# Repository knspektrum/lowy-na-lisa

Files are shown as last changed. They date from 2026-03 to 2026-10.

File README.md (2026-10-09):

# Łowy na Lisa

Gra terenowa dla dzieci oparta na LoRa - polega na znalezieniu ukrytych nadajnikiów ("lisów") wykorzystując siłę sygnału radiowego

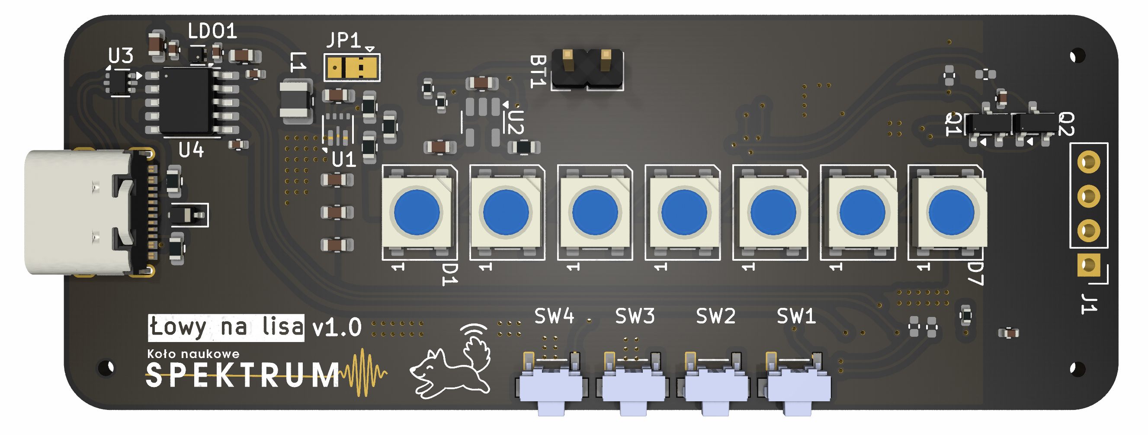
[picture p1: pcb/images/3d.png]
3D render PCB


## O projekcie

"Łowy na Lisa" to otwarty projekt hardware'owy tworzący ręczne urządzenia do polowania na nadajniki LoRa. Każdy uczestnik otrzymuje kompaktowe urządzenie wyposażone w:

- Wyświetlacz OLED z animowaną mascotką lisa (szczęśliwy smutny w zależności od siły sygnału)
- Pasek 7 diod WS2812B pokazujących kierunek i siłę sygnału
- 4 przyciski do obsługi menu
- Obsługę baterii LiPo z ładowaniem przez USB-C
- Tryb głębokiego snu dla długiej pracy na baterii

### Hardware
- **MCU:** CubeCell HTCC-AM01
- **LEDy:** 7x WS2812B NeoPixel (adresowalne)
- **Wyświetlacz:** 0.96" OLED I2C
- **Przyciski:** 4x na boku
- **Zasilanie:** Bateria LiPo ~500mAh + ładowarka TP4054
- **USB:** USB-C z konwerterem CH340K (programowanie)
- **Antena:** 868MHz, Własnoręcznie stworzona przez nas antena yagi (wczesniej zewnętrzna antena yagi telewizyjna) 
- **Wymiary:** Podłużna obudowa przyjazna dla dzieci

## Wersje

- [Odbiornik na PCB (CubeCell)](#pcb) - docelowa wersja na własnej płytce
- [Nadajnik ESP32](software/fox-transmitter/README.md) - "lis": WeMos D1 R32 + HM-TRLR-D-TTL-868, zasilanie 5x AA
- [Odbiornik ESP32](software/led-receiver/README.md) - ESP32 + Seeed LoRa-E5 + 7 diod, zasilanie LiPo
- [Flota i aktualizacje](software/ota/README.md) - strona w Chrome: które urządzenia ESP32 są włączone, na jakim kanale i programie; podpisane aktualizacje przez Bluetooth

<details>
<summary><b>Odbiornik na PCB (CubeCell)</b> - schemat i plot</summary>

Plot  |  Schemat
:-------------------------:|:-------------------------:
Plot  |  Schemat

Program: [software/receiver](software/receiver/receiver.ino)

</details>

<details>
<summary><b>Nadajnik ESP32</b> - schemat połączeń i kanały</summary>

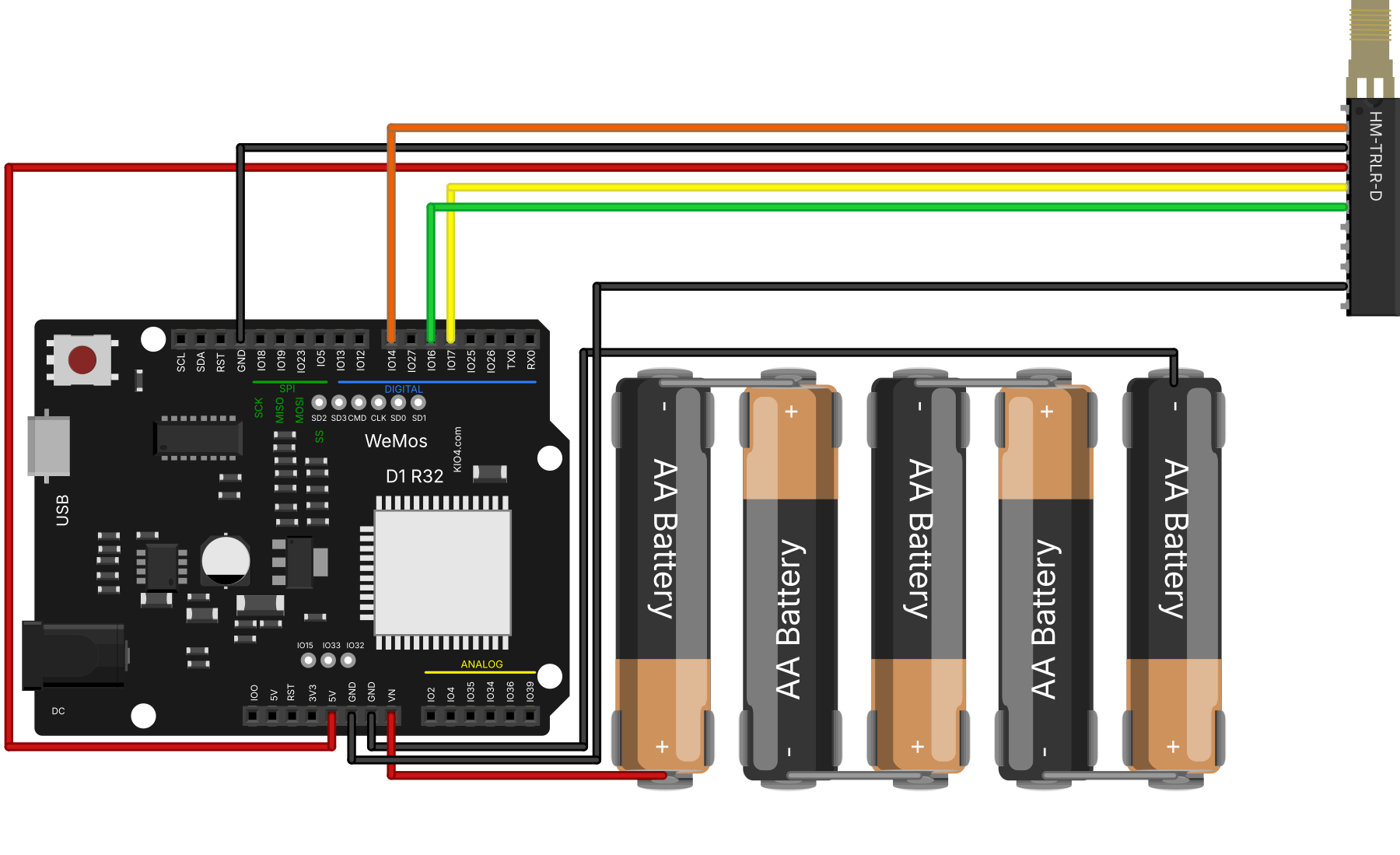
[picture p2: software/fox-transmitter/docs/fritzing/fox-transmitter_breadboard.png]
Nadajnik


D1 R32  |  HM-TRLR-D / baterie  |  Opis
:-------------------------:|:-------------------------:|:-------------------------
IO17 (TX)  |  RXD  |  komendy AT i dane do modułu
IO16 (RX)  |  TXD  |  odpowiedzi modułu
IO14  |  CONFIG  |  LOW = konfiguracja (AT), HIGH = nadawanie
5V  |  5V  |  zasilanie modułu
GND (górny, obok IO18)  |  GND (górny)  |
GND (dolny)  |  SLEEP  |  SLEEP na GND = moduł nie zasypia
VIN  |  + baterii 5x AA  |  ok. 7.5 V
GND (obok VIN)  |  - baterii  |

Id  |  Częstotliwość  |  Zworki CH_1-CH_4 (od góry)
:-------------------------:|:-------------------------:|:-------------------------:
1  |  863.0 MHz  |  ○ ○ ○ ○
2  |  863.5 MHz  |  ● ○ ○ ○
3  |  864.0 MHz  |  ○ ● ○ ○
4  |  864.5 MHz  |  ● ● ○ ○
5  |  865.0 MHz  |  ○ ○ ● ○
6  |  865.5 MHz  |  ● ○ ● ○
7  |  866.0 MHz  |  ○ ● ● ○
8  |  866.5 MHz  |  ● ● ● ○

Programowanie i szczegóły: [software/fox-transmitter](software/fox-transmitter/README.md)

</details>

<details>
<summary><b>Odbiornik ESP32</b> - schemat połączeń</summary>

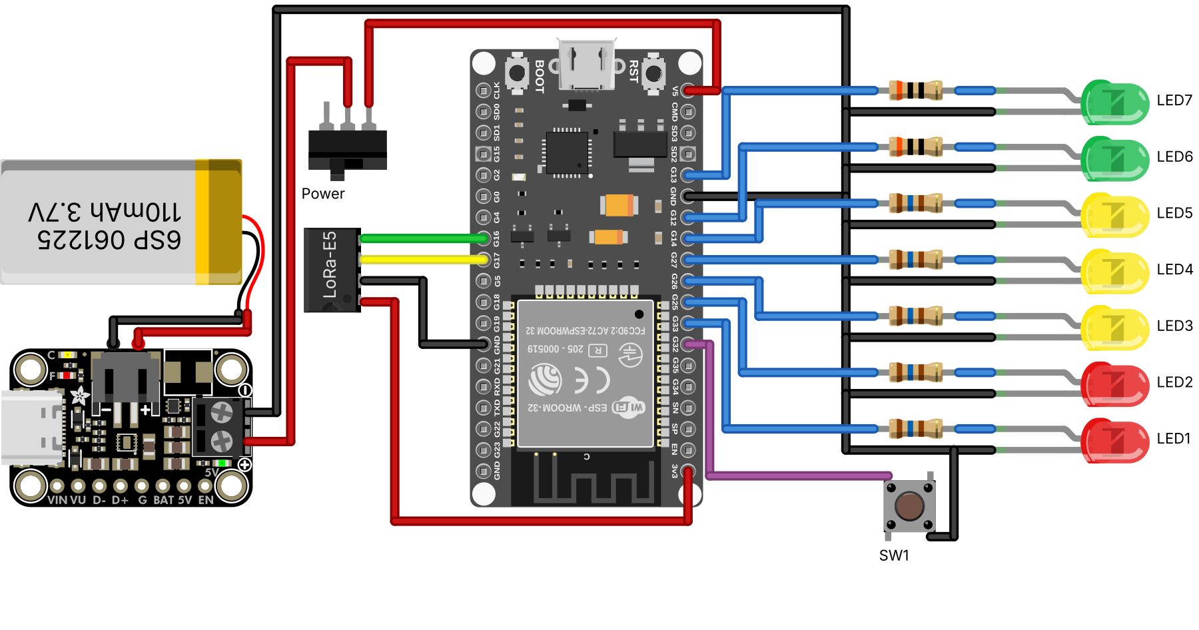
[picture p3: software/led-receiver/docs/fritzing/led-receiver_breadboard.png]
Odbiornik


ESP32  |  Element  |  Opis
:-------------------------:|:-------------------------:|:-------------------------
G33, G25  |  LED1, LED2 (czerwone)  |  rezystor 160 Ω
G26, G27, G14  |  LED3-LED5 (żółte)  |  rezystor 160 Ω
G12, G13  |  LED6, LED7 (zielone)  |  rezystor 30 Ω
G32  |  przycisk  |  drugi pin do GND
G17 (TX2)  |  LoRa-E5 RX (pad 9)  |  komendy AT
G16 (RX2)  |  LoRa-E5 TX (pad 10)  |  odpowiedzi i pakiety
3V3, GND  |  LoRa-E5 VCC (pad 1), GND (pad 2)  |
V5  |  wyłącznik → przetwornica 5 V → LiPo  |

Obsługa i programowanie: [software/led-receiver](software/led-receiver/README.md)

</details>

## PCB

Projekt PCB znajduje się w katalogu `pcb/` i jest przygotowany pod produkcję w JLCPCB (z PCBA assembly).

[Model 3D](pcb/lowy-na-lisa.stl)

Plot  |  Schemat
:-------------------------:|:-------------------------:
Plot  |  Schemat

## Historia projektu

### Faza 1: Eksperymenty
- Testy modułów nRF905 - działają ale brak RSSI
- Przejście na moduły HM-TRLR-D-TTL-868 (LoRa/FSK/GFSK + RSSI)
- Brute-forceowanie komend AT modemu LoRa

### Faza 2: Targi Hobby
- Pierwsza działająca wersja
- Testy z dziećmi - obudowa sprawdza się, anteny za duże
- Problem: nadajniki się zakłócały (rozwiązane: różne kanały)
- Pozytywne wrażenia: światełka wzbudzają zainteresowanie

### Faza 3: PCB
- Projekt PCB zintegrowanego z modułem CubeCell
- Optymalizacja pod baterię (deep sleep, odcięcie LEDów)
- Przygotowanie pod produkcję SMT w JLCPCB

## Pomysły/Plany na rozwój

- **Tryby gry:**
  - Zdobywanie nadajników (zbliżenie się + potwierdzenie przyciskiem)
  - Rywalizacja (broadcast pozycji na innym kanale)
  - Tryb fabularny z questami

- **Animacje:**
  - Lis wyskakujący z krzaka przy zbliżeniu do nadajnika
  - Wizualizacja siły sygnału na ekranie i LEDach
  - Różne stany emocjonalne mascotki

- **Hardware:**
  - Własnoręcznie robione anteny DIY
  - Ulepszona obudowa z integracją PCB
  - Druk 3D

## Autorzy

- Hubert Mucha - Antena
- Antoni Sacewicz - Antena
- Judyta Ferenc - Antena
- Antoni Antosik - obudowa 3D
- Adrian Bruch - Animacje i interfejs ekranu
- Katarzyna Rybarkiewicz - Lider, Projekt PCB
- Maximilian Gaedig - Aktualny Lider, Projekt PCB, Software
# na rekrutacji

wiktor kandulski, discord: kandul - marketing, kolaboracja z harcerstwem
tymoteusz majorek, discord: tymoteuszu - materiały marketingowe/instrukcje - pisanie zaawansowane (pisał kśiążki), 3D
beata waligórska, discord: slaani. - animacje

## Licencja

GPLv3

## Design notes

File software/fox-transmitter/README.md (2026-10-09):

# Nadajnik ("lis")

Nadajnik wysyła co 100 ms pakiet LoRa ze swoim numerem (id 1-9). Odbiorniki ustawione na ten sam numer pokazują siłę jego sygnału na diodach. Id 9 wymaga binarnego trybu diod w odbiorniku.

Schemat połączeń

## Hardware
- **MCU:** WeMos D1 R32 (ESP32, format Arduino Uno)
- **Radio:** HopeRF HM-TRLR-D-TTL-868 (LoRa SF7, 125 kHz, 20 dBm, pakiety po 32 bajty)
- **Zasilanie:** 5x AA (ok. 7.5 V) na VIN i GND

## Połączenia

D1 R32  |  HM-TRLR-D  |  Opis
:-------------------------:|:-------------------------:|:-------------------------
IO17 (TX)  |  RXD  |  komendy AT i dane do modułu
IO16 (RX)  |  TXD  |  odpowiedzi modułu
IO14  |  CONFIG  |  LOW = tryb konfiguracji (AT), HIGH = nadawanie
5V  |  5V  |  moduł przyjmuje 3.3-5.5 V
GND (górny, obok IO18)  |  GND (górny)  |
GND (dolny)  |  SLEEP  |  SLEEP na GND = moduł nie zasypia

D1 R32  |  Baterie 5x AA  |  Opis
:-------------------------:|:-------------------------:|:-------------------------
VIN  |  +  |  ok. 7.5 V (nowe baterie do ok. 8 V)
GND (obok VIN)  |  -  |

Piny modułu od góry: STATUS, CONFIG, GND, 5V, RXD, TXD, GND, A_TX, B_RX, SLEEP, RESET. Na górze modułu jest gniazdo antenowe SMA (żeńskie). STATUS, drugi GND, A_TX, B_RX i RESET nie są podłączone.

## Kanały

Numer nadajnika (id) wyznacza kanał radiowy i zawartość pakietów:
- **Kanał:** id - 1, ustawiany tylko zworkami CH_1-CH_4 na module (żadna komenda AT go nie ustawia ani nie odczytuje)
- **Częstotliwość:** 863.0 MHz + 0.5 MHz × kanał
- **Sync word:** `CAFE` + 4× id + `BABE`, zapisany w module
- **Pakiet:** 32 bajty, każdy równy id

Id  |  Kanał |  Częstotliwość |  Sync word |  Kod binarny (LED4–LED7)
:---:|:---:|:---:|:---:|:---:
1 | 0 | 863.0 MHz | `CAFE01010101BABE` | `0001`
2 | 1 | 863.5 MHz | `CAFE02020202BABE` | `0010`
3 | 2 | 864.0 MHz | `CAFE03030303BABE` | `0011`
4 | 3 | 864.5 MHz | `CAFE04040404BABE` | `0100`
5 | 4 | 865.0 MHz | `CAFE05050505BABE` | `0101`
6 | 5 | 865.5 MHz | `CAFE06060606BABE` | `0110`
7 | 6 | 866.0 MHz | `CAFE07070707BABE` | `0111`
8 | 7 | 866.5 MHz | `CAFE08080808BABE` | `1000`
9 | 8 | 867.0 MHz | `CAFE09090909BABE` | `1001`

Odbiornik startuje na id 1, każde naciśnięcie przycisku przechodzi na następny numer, a po ostatnim wraca do 1. Liczbę numerów (domyślnie 7, maksymalnie 9 w trybie binarnym) i sposób ich wyświetlania ustawia się na [stronie floty](../ota/README.md); szczegóły w [software/led-receiver](../led-receiver/README.md#ustawienia). Kod binarny podano od LED4 do LED7: `1001` oznacza zapalone LED4 i LED7. Zamiast przycisku można wpisać cyfrę w monitorze portu szeregowego odbiornika.

### Zworki

Zworki od góry do dołu, ● = założona, ○ = brak (kanał zapisany binarnie: CH_1 = 1, CH_2 = 2, CH_3 = 4, CH_4 = 8):

Zworka | Id 1 | Id 2 | Id 3 | Id 4 | Id 5 | Id 6 | Id 7 | Id 8 | Id 9
:---:|:---:|:---:|:---:|:---:|:---:|:---:|:---:|:---:|:---:
CH_1 | ○ | ● | ○ | ● | ○ | ● | ○ | ● | ○
CH_2 | ○ | ○ | ● | ● | ○ | ○ | ● | ● | ○
CH_3 | ○ | ○ | ○ | ○ | ● | ● | ● | ● | ○
CH_4 | ○ | ○ | ○ | ○ | ○ | ○ | ○ | ○ | ●

## Bluetooth

Lis nadaje przez Bluetooth na [stronę](../ota/README.md) swój kanał, wersję programu i stan. Telefon z aplikacją do Bluetooth też go widzi i mógłby po sile sygnału namierzyć lisa, więc w **Ustawieniach** lisa na stronie można włączyć ukrywanie: lis milknie 10, 30 albo 60 minut po włączeniu. Domyślnie nie ukrywa się nigdy. Ukryty lis jest na stronie „wyłączony albo ukryty”; żeby go sprawdzić albo zaktualizować, trzeba go wyłączyć i włączyć. Lis nie milknie, dopóki strona jest z nim połączona albo trwa aktualizacja.

## Programowanie

1. Ustaw zworki CH_1-CH_4 dla wybranego id (tabela wyżej).
2. Podłącz D1 R32 przez USB i wgraj program (następne wersje można wgrywać przez Bluetooth, [software/ota](../ota/README.md)):
   ```bash
   software/ota/build.sh
   software/ota/usb-flash.sh transmitter /dev/ttyUSB0
   ```
3. Otwórz monitor portu szeregowego (115200 baud) i wpisz cyfrę id (1-9). Nadajnik odpowiada `updated transmitter id id=N sync_word=CAFE...BABE`.
4. Wpisz `w`, żeby zapisać ustawienia w module (`saved to flash`). Po każdym starcie program odczytuje sync word z modułu i używa zapisanego id.
5. Sprawdź na odbiorniku ustawionym na to samo id: diody pokazują siłę sygnału, a w monitorze odbiornika pojawia się `received packet ... packet_tx_id=N`.

## Pliki

- `fox-transmitter.ino` - program nadajnika (aktualizacje przez Bluetooth: biblioteka `software/libraries/LisekOta`)
- `docs/fritzing/` - schemat połączeń we Fritzingu (`fox-transmitter.fzz`), generowany przez `make_fzz.py`, eksport `build.sh`
- Płytka WeMos D1 R32 we Fritzingu: część autorstwa Petera Van Eppa ([forum Fritzing](https://forum.fritzing.org/t/looking-for-wemos-d1-r32-esp32-uno/14487)); moduł HM-TRLR-D jest narysowany jako ogólny układ SIP z pinami w tej samej kolejności co na module, gniazdo SMA to część "SMA Antenna Connector" Petera Van Eppa ([forum Fritzing](https://forum.fritzing.org/t/sma-female-connector-part/4688)), baterie jako 5 ogniw AA z biblioteki Fritzinga połączonych szeregowo

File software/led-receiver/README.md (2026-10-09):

# Odbiornik z diodami

Odbiornik nasłuchuje nadajnika o wybranym numerze (id 1-9) i pokazuje siłę jego sygnału na 7 diodach. Działa tak samo jak `software/receiver/receiver.ino`, tylko na ESP32 z modułem Seeed LoRa-E5 sterowanym komendami AT.

Schemat połączeń

## Hardware
- **MCU:** ESP32 DevKit (38 pinów, wersja szeroka)
- **Radio:** Seeed LoRa-E5 (STM32WLE5JC, firmware AT, UART 9600 baud)
- **LEDy:** 7x 5 mm: 2 czerwone, 3 żółte, 2 zielone
- **Przycisk:** zmiana numeru nadajnika
- **Zasilanie:** Bateria LiPo + płytka z ładowaniem USB-C i przetwornicą 5 V, wyłącznik na plusie

## Połączenia

ESP32  |  Element  |  Opis
:-------------------------:|:-------------------------:|:-------------------------
G33  |  LED1 (czerwona)  |  najsłabszy sygnał, rezystor 160 Ω
G25  |  LED2 (czerwona)  |  rezystor 160 Ω
G26  |  LED3 (żółta)  |  rezystor 160 Ω
G27  |  LED4 (żółta)  |  rezystor 160 Ω
G14  |  LED5 (żółta)  |  rezystor 160 Ω
G12  |  LED6 (zielona)  |  rezystor 30 Ω
G13  |  LED7 (zielona)  |  najsilniejszy sygnał, rezystor 30 Ω
G32  |  przycisk  |  drugi pin do GND (wewnętrzny pull-up)
G17 (TX2)  |  LoRa-E5 RX (pad 9, PB7)  |  komendy AT
G16 (RX2)  |  LoRa-E5 TX (pad 10, PB6)  |  odpowiedzi i odebrane pakiety
3V3  |  LoRa-E5 VCC (pad 1)  |
GND  |  LoRa-E5 GND (pad 2), katody LED, przycisk  |
V5  |  wyłącznik → wyjście 5 V przetwornicy  |  bateria → ładowarka/przetwornica → wyłącznik → V5

Każda dioda: pin → rezystor → anoda, katoda → GND. Antena do RFIO modułu (pad 15).

## Obsługa

- Po starcie odbiornik słucha nadajnika 1 (863.0 MHz)
- Krótkie naciśnięcie przycisku: następny nadajnik (po ostatnim kanale wraca do 1); przez 0.5 s diody pokazują nowe id
- Cyfra w monitorze portu szeregowego (115200 baud) robi to samo
- Liczba zapalonych diod (od LED1) = siła sygnału: (110 + RSSI) / 15
- Brak pakietu od wybranego nadajnika przez 1 s: diody gasną (nadajnik wysyła co 100 ms)
- Aktualizacja przez Bluetooth: diody zapalają się kolejno w miarę wgrywania

Kanały i ustawianie nadajników: [software/fox-transmitter](../fox-transmitter/README.md).

### Ustawienia

Ustawia się je tylko w **Ustawieniach** odbiornika na [stronie floty](../ota/README.md), więc nie da się ich zmienić przypadkiem na samym odbiorniku. Odbiornik pamięta je po wyłączeniu.

- **Liczba kanałów:** przez ile numerów nadajników przechodzi przycisk, domyślnie 7 (1-7)
- **Diody zwykłe** (domyślnie): zapala się tyle diod od LED7 w dół, ile wynosi id, więc najwyżej 7 kanałów
- **Diody binarne:** id zapisane dwójkowo, do 9 kanałów, ● = świeci

Id | LED4 (8) | LED5 (4) | LED6 (2) | LED7 (1) | Kod
:--:|:--:|:--:|:--:|:--:|:--:
1 | ○ | ○ | ○ | ● | `0001`
2 | ○ | ○ | ● | ○ | `0010`
3 | ○ | ○ | ● | ● | `0011`
4 | ○ | ● | ○ | ○ | `0100`
5 | ○ | ● | ○ | ● | `0101`
6 | ○ | ● | ● | ○ | `0110`
7 | ○ | ● | ● | ● | `0111`
8 | ● | ○ | ○ | ○ | `1000`
9 | ● | ○ | ○ | ● | `1001`

Jeśli wybrane id nie mieści się w nowych ustawieniach (mniej kanałów albo id 8–9 przy zwykłych diodach), odbiornik wraca do id 1.

## Programowanie

Pierwszy raz przez USB, potem przez Bluetooth ze strony floty: [software/ota](../ota/README.md).

```bash
software/ota/build.sh
software/ota/usb-flash.sh receiver /dev/ttyUSB0
```

## Pliki

- `led-receiver.ino` - program odbiornika (aktualizacje przez Bluetooth: biblioteka `software/libraries/LisekOta`)
- `docs/fritzing/` - schemat połączeń we Fritzingu (`led-receiver.fzz`), generowany przez `make_fzz.py` (wartości rezystorów: `R_RED_YELLOW`, `R_GREEN`), eksport `build.sh`
- Płytka ESP32 we Fritzingu: część `ESP32-38PinWide-fixed` autorstwa Thomasa Plunketta ([forum Fritzing](https://forum.fritzing.org/t/esp32-wroom-32u/12978)), z poprawionym opisem pinu CMD obok V5; LoRa-E5 jest narysowany jako ogólny układ SIP (piny od góry: TX, RX, GND, VCC), ładowarka jako Adafruit bq25185 + 5V boost
- Wspólne skrypty Fritzinga: `software/fritzing-lib/` (`make_fzz.py` sprawdza, czy przewody się nie krzyżują ani nie nakładają; masa może przechodzić pod przewodami diod)

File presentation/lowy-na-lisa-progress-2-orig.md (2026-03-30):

# Łowy na Lisa - Update 15.01.26

## targi hobby
- pierwsza działająca wersja/prezentacja dla dzieci
- zauważenie że antena za duża dla dzieci
- dobre wrażenie - obudowa poręczna
- dobra dekoracja
- swiatełka wzbudzały zainteresowanie

## nadajniki się zakłucały
- było tylko odróżnianie po id wysyłanym w pakiecie lora
- nadawały były na tym samym kanale
- prosty fix: różne kanały

## plany na przyszłość 

### ekran
- maskotka lisek
- wizualizacja sygnału (lisek smutny/sczęsliwy)
- zmiana kalibracji
- ekran z deltalami: snr/rssi / detale na main screen
- stan baterii
- hint obsługi

#### animacje
- animacja jak sie dojdzie do nadajnika będzie karton, karton się otworzy i lis wyskoczy

### własnoręcznie robione anteny DIY
- druty
- kable
- druk 3d :)

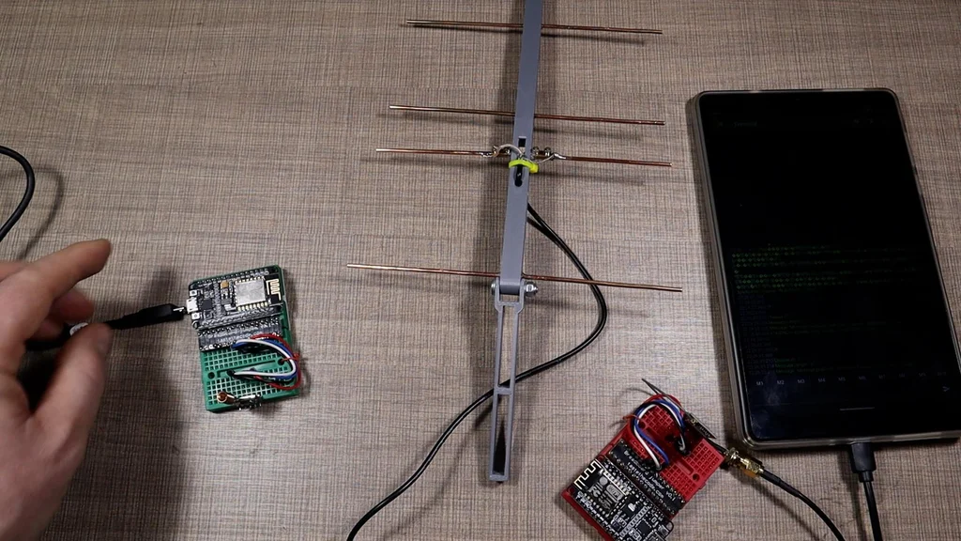
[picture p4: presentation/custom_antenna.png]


### kalibracja
- przy resetcie?

#### pomysły na zabawe
- zdobywanie nadajników (nadajnik blisko + potwierdzenie guzikiem) (przeskoczenie na następny kanał?)
- rywalizacja (broadcast aktualnego poziomu/nadajnika na innym kanale)
- story wymysleć

### polepszenie obudowy
- integracja pcb

### pcb
- stan baterii (voltage divider)
- ładowanie (moduł tpXXXX) + usb c
- Regulator LDO bateria -> 3.3v
- integracja z modułami CubeCell AM01
- podłączenie do anteny U.FL Receptacle jest już integrowane w CubeCell
- ledy + rezystory
- złącze na ekran
- złącza na guziki (reset + menu1 + menu2)

## dalszy plan
- 25.02.26 środa spotkanko 17:00 - pcb v1 i test antena
- 05.03.26 pcb final - zamówienie
- 25.03.26 spotkanko, zkładanie, lutowanie

## pytania?

## rozłożenie zadań
- animacje/pixelizacja liska - Adrian - do 15.03.26
- pcb - v1 Kasia - do 25.02.26 - muszę podać plan pinów 
- antena - Hubert + Antek - do 25.02.26 (blocked by order + druk (Max))
- programowanko - Adrian i Max - bez stanu bateri do 15.03.26 - dodanie stanu bateri do 30.03.26
- story - Antek
- obudowa - Antek3D (blocked by pcb (Kasia))
### cel - noc naukowców - wrzesień

## plan prezentacji
- Hubert - targi hobby
- Max - zakułucanie się nadajników
- Adrian - animacje/interfejs ekranu

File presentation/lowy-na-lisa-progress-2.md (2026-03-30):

---
theme:
  override:
    code:
      alignment: left
      background: false
---

Łowy na Lisa - Update 15.01.26
====
- targi hobby
- nadajniki się zakłucały
- plany na przyszłość

<!-- end_slide -->

targi hobby
===
- pierwsza działająca wersja/prezentacja dla dzieci
- zauważenie że antena za duża dla dzieci
- dobre wrażenie - obudowa poręczna
- dobra dekoracja
- swiatełka wzbudzały zainteresowanie

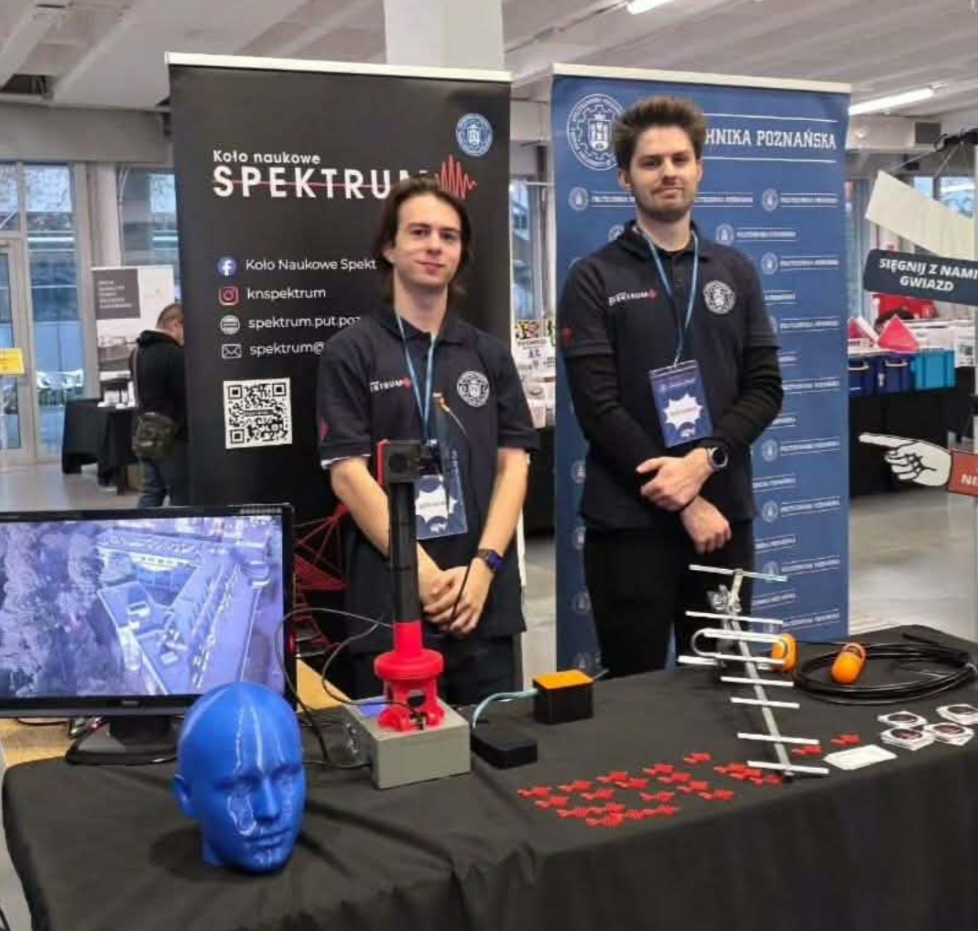
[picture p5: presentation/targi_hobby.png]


<!-- end_slide -->

nadajniki się zakłucały
===
- było tylko odróżnianie po id wysyłanym w pakiecie lora
- nadawały były na tym samym kanale
- prosty fix: różne kanały

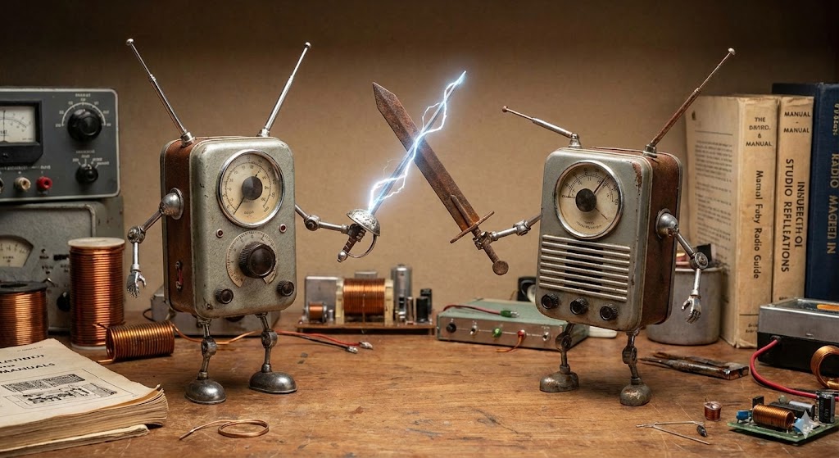
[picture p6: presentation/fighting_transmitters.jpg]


<!-- end_slide -->

plany na przyszłość
===
- ekran
- animacje
- antena
- pcb

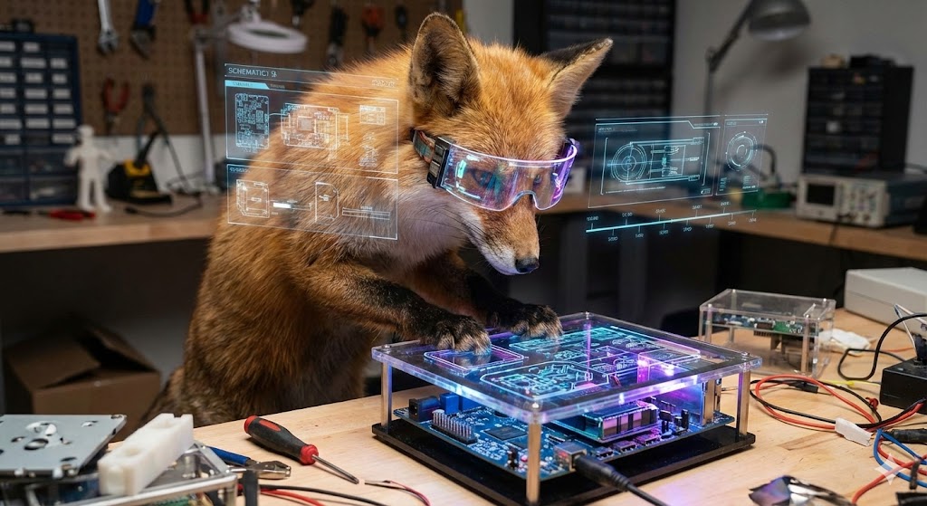
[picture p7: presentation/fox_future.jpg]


<!-- end_slide -->

ekran
===
- maskotka lisek
- wizualizacja sygnału (lisek smutny/sczęsliwy)
- zmiana kalibracji
- ekran z deltalami: snr/rssi / detale na main screen
- stan baterii
- hint obsługi

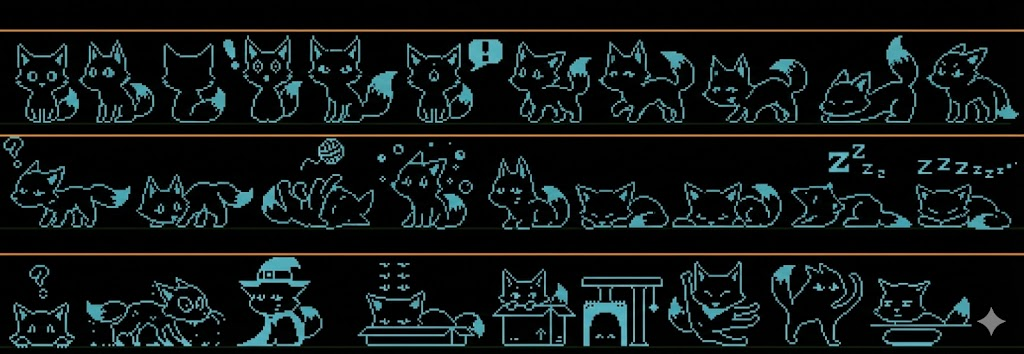
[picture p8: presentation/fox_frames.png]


<!-- end_slide -->

## własnoręcznie robione anteny DIY
- druty
- kable
- druk 3d :)



<!-- end_slide -->

#### pomysły na zabawe
- zdobywanie nadajników (nadajnik blisko + potwierdzenie guzikiem) (przeskoczenie na następny kanał?)
- rywalizacja (broadcast aktualnego poziomu/nadajnika na innym kanale)
- story wymysleć

## polepszenie obudowy
- integracja pcb

<!-- end_slide -->

pcb
===
- stan baterii (voltage divider)
- ładowanie (moduł tpXXXX) + usb c
- Regulator LDO bateria -> 3.3v
- integracja z modułami CubeCell AM01
- podłączenie do anteny U.FL Receptacle jest już integrowane w CubeCell
- ledy + rezystory
- złącze na ekran
- złącza na guziki (reset + menu1 + menu2)

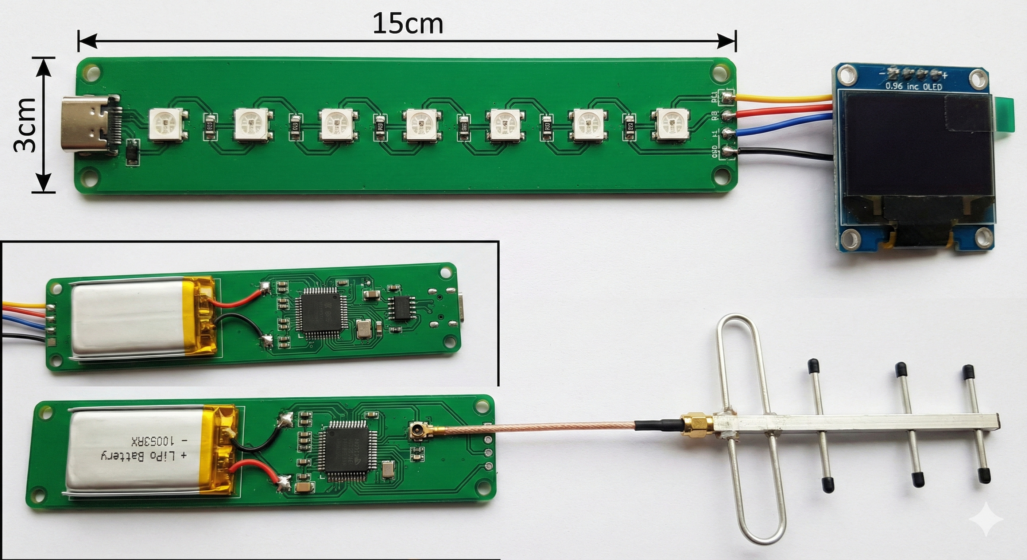
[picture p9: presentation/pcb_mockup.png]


<!-- end_slide -->

dalszy plan
===
- 25.02.26 środa spotkanko 17:00 - pcb v1 i test antena
- 05.03.26 pcb final - zamówienie
- 25.03.26 spotkanko, zkładanie, lutowanie
- wrzesień - noc naukowców

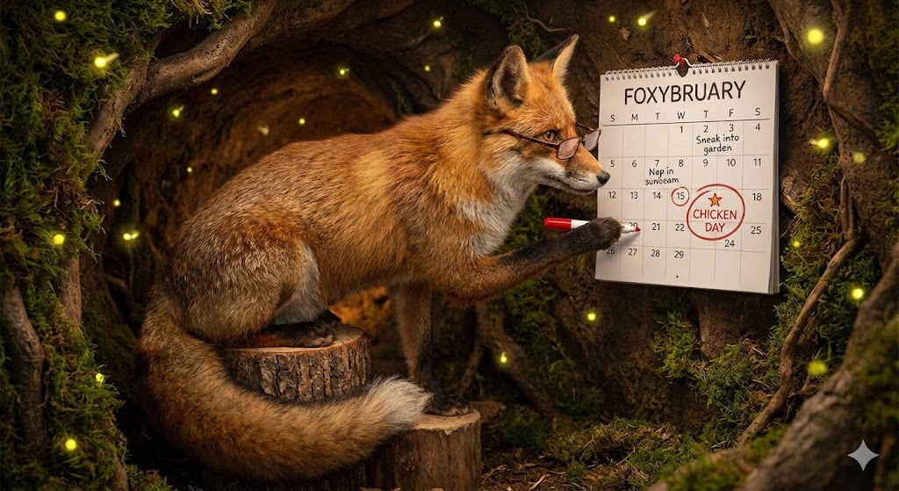
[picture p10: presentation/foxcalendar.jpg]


<!-- end_slide -->

# pytania?

<!-- end_slide -->

<!-- end_slide -->
<!-- end_slide -->
<!-- end_slide -->
<!-- end_slide -->

### cel - noc naukowców - wrzesień

<!-- end_slide -->

## kalibracja
- przy resetcie?
#### animacje
- animacja jak się jest blisko do nadajnika - będzie karton, karton się otworzy i lis wyskoczy

# rozłożenie zadań
- animacje/pixelizacja liska - Adrian - do 15.03.26
- pcb - v1 Kasia - do 25.02.26 - muszę podać plan pinów
- antena - Hubert + Antek - do 25.02.26 (blocked by order + druk (Max))
- programowanko - Adrian i Max - bez stanu bateri do 15.03.26 - dodanie stanu bateri do 30.03.26
- story - Antek
- obudowa - Antek3D (blocked by pcb (Kasia))

# plan prezentacji
- Hubert - targi hobby
- Max - zakułucanie się nadajników
- Adrian - animacje/interfejs ekranu

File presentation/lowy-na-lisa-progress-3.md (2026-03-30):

pomysł animacji: wyskakiwanie z krzaka 

Gemini
Analiza i poprawki projektu elektroniki
Conversation with Gemini
You said
co bys jescze dodal, analize mocnom

Gemini said
Projekt wygląda na fajny start (LoRa + RGB to klasyka "smart" gadżetów), ale diabeł tkwi w szczegółach, szczególnie przy zasilaniu bateryjnym. Masz tam kilka "pułapek", które mogą spalić komponenty lub rozładować baterię w jeden dzień.

Oto konkretna analiza i lista tego, co warto dodać/poprawić:

1. Krytyczne poprawki (Błędy w schemacie)
Kondensatory przy przyciskach (C1-C4): Masz wpisane 100µF. To o kilka rzędów wielkości za dużo. Standardowo do debouncingu (oddrgania styków) daje się 10nF - 100nF. Przy 100µF, w momencie naciśnięcia przycisku, następuje zwarcie dużego ładunku do masy, co z czasem wypali styki przycisku, a czas ładowania przez rezystor podciągający będzie trwał wieki.

Linia Reset: Dodaj rezystor podciągający (Pull-up, np. 10k) do 3.3V, chyba że moduł AM01 ma go już wewnętrznie (warto sprawdzić w datasheet, ale zewnętrzny to dobra praktyka dla stabilności).

Brak kondensatorów odsprzęgających: Przy pinie VDD procesora (AM01) i przy złączu wyświetlacza koniecznie dodaj kondensatory ceramiczne 100nF (i jeden 10µF blisko procka). Bez nich układ może się resetować przy skokach poboru prądu (np. podczas wysyłki pakietu LoRa).

2. Zarządzanie energią (Kluczowe przy baterii)
Odcięcie zasilania LED (VCC_LED): Diody WS2812B "piją" prąd (ok. 1mA na diodę) nawet gdy nie świecą (tzw. quiescent current). Przy 7 diodach masz 7mA stałego poboru, co zabije baterię 1000mAh w kilka dni bez robienia czegokolwiek.

Rozwiązanie: Dodaj tranzystor P-MOSFET (jako High-Side Switch), który pozwoli procesorowi całkowicie odciąć zasilanie od paska LED, gdy nie jest używany.

Dzielnik napięcia do baterii: Masz to w TODO. Użyj dużych rezystorów (np. 100k + 100k), żeby sam dzielnik nie rozładowywał baterii. Dodaj też tranzystor sterujący dzielnikiem lub kondensator 100nF przy pinie ADC, żeby pomiar był stabilny.

Level Shifter dla LED: WS2812B zasilane z 5V (Step-up) mogą nie wykryć sygnału 3.3V z procesora jako logicznej "jedynki" (wymagają ok. 0.7 * VCC).

Rozwiązanie: Prosty konwerter poziomów na jednym tranzystorze lub diodzie i rezystorze, żeby podbić sygnał GPIO2 do 5V.

3. Część RF (LoRa)
Tor antenowy (Pin 22): Na schemacie pin ANT jest pusty. Musisz tam dodać:

Złącze U.FL (IPEX) lub SMA.

Miejsce na tzw. Pi-network (trzy elementy: kondensator-cewka-kondensator), aby móc dopasować antenę do 50 Ohm. Nawet jeśli wlutujesz tam tylko zworkę 0 Ohm, miejsce na PCB musi być.

4. Co warto jeszcze dodać?
Zabezpieczenie przed odwrotną polaryzacją: Na złączu baterii (J3) łatwo o pomyłkę. Dodaj diodę Schottky’ego o niskim spadku napięcia lub (lepiej) tranzystor P-MOSFET jako zabezpieczenie.

Dioda statusowa LED (zwykła): Oprócz paska RGB, jedna mała dioda LED (np. na GPIO4) jest nieoceniona przy debugowaniu, gdy chcesz oszczędzać prąd i nie włączać całego paska ani wyświetlacza.

Piny I2C Pull-up: Jeśli Twój wyświetlacz (J1) nie ma wbudowanych rezystorów 4.7k na liniach SDA/SCL, musisz je dodać na schemacie.

USB-C i Ochrona ESD: Skoro planujesz USB, dodaj dedykowany układ zabezpieczający (ESD protection) na linie danych D+/D- oraz przyciski. To groszowe sprawy, a ratują procek przed ładunkami z palców.

5. Uwagi do TODO użytkownika
Step-Up na 5V: Pamiętaj, że przetwornice Step-Up wprowadzają szum. Daj spore kondensatory na wyjściu, żeby pasek LED nie zakłócał odczytów ADC lub komunikacji radiowej.

LDO: Wybierz model o bardzo niskim prądzie spoczynkowym (Low Iq), np. seria MCP1700 lub XC6206, jeśli urządzenie ma spać przez większość czasu.

Podsumowując: Najważniejsza rzecz teraz to zmiana tych kondensatorów 100µF przy buttonach na 100nF i dodanie odcięcia zasilania dla LEDów. Inaczej Twój projekt "zje" baterię szybciej, niż zdążysz wysłać pierwszy pakiet LoRa.

Czy chcesz, żebym pomógł Ci dobrać konkretne wartości rezystorów do dzielnika baterii lub zaprojektował schemat odcięcia zasilania LED na MOSFETcie?

Gemini is AI and can make mistakes, including about people. Your privacy and GeminiOpens in a new window

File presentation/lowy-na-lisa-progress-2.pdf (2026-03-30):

# Łowy na Lisa - Update 15.01.26

- targi hobby
- nadajniki się zakłucały
- plany na przyszłość

# targi hobby

- pierwsza działająca wersja/prezentacja dla dzieci
- zauważenie że antena za duża dla dzieci
- dobre wrażenie - obudowa poręczna
- dobra dekoracja
- swiatełka wzbudzały zainteresowanie

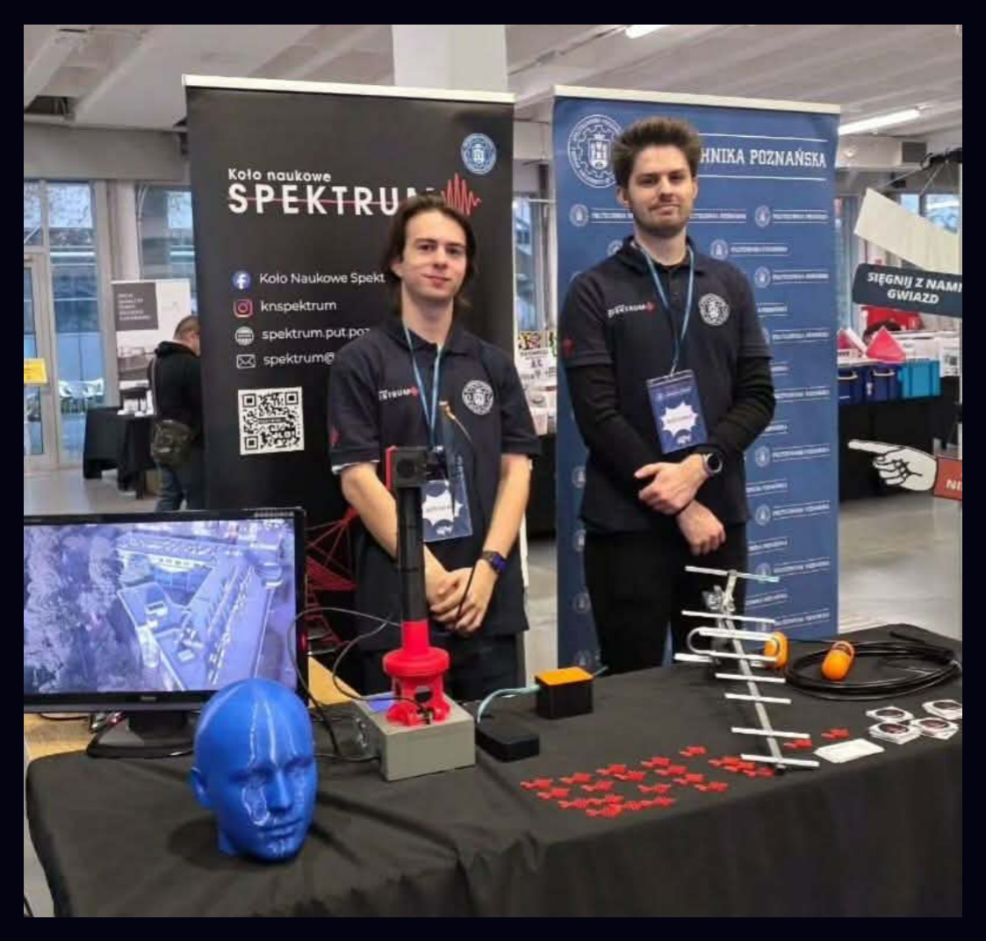
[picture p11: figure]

# nadajniki się zakłucały

- było tylko odróżnianie po id wysyłanym w pakiecie lora
- nadawały były na tym samym kanale
- prosty fix: różne kanały


# plany na przyszłość

- ekran
- animacje
- antena
- pcb

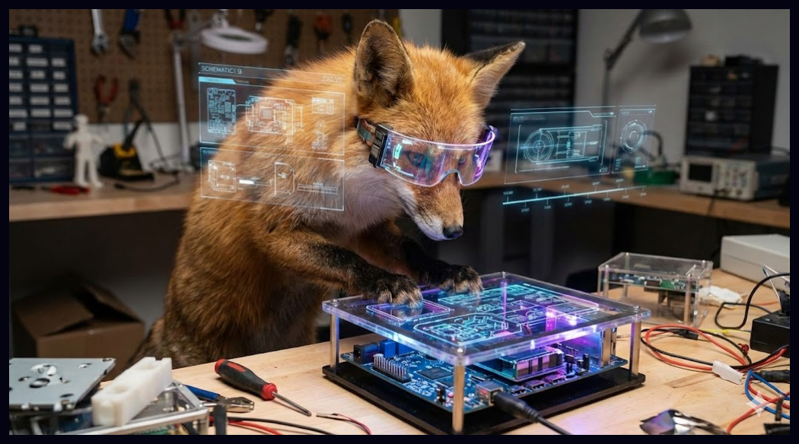
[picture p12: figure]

# ekran

- maskotka lisek
- wizualizacja sygnału (lisek smutny/sczęsliwy)
- zmiana kalibracji
- ekran z deltalami: snr/rssi / detale na main screen
- stan baterii
- hint obsługi

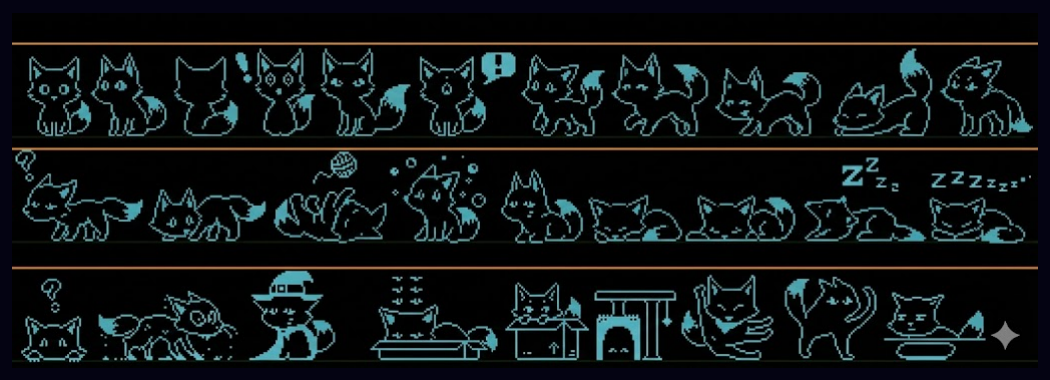
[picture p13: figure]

▓▓▓ własnoręcznie robione anteny DIY

- druty
- kable
- druk 3d :)


░░░░░ pomysły na zabawe

- zdobywanie nadajników (nadajnik blisko + potwierdzenie guzikiem) (przeskoczenie na następny kanał?)
- rywalizacja (broadcast aktualnego poziomu/nadajnika na innym kanale)
- story wymysleć

▓▓▓ polepszenie obudowy

- integracja pcb

# pcb

- stan baterii (voltage divider)
- ładowanie (moduł tpXXXX) + usb c
- Regulator LDO bateria -> 3.3v
- integracja z modułami CubeCell AM01
- podłączenie do anteny U.FL Receptacle jest już integrowane w CubeCell
- ledy + rezystory
- złącze na ekran
- złącza na guziki (reset + menu1 + menu2)

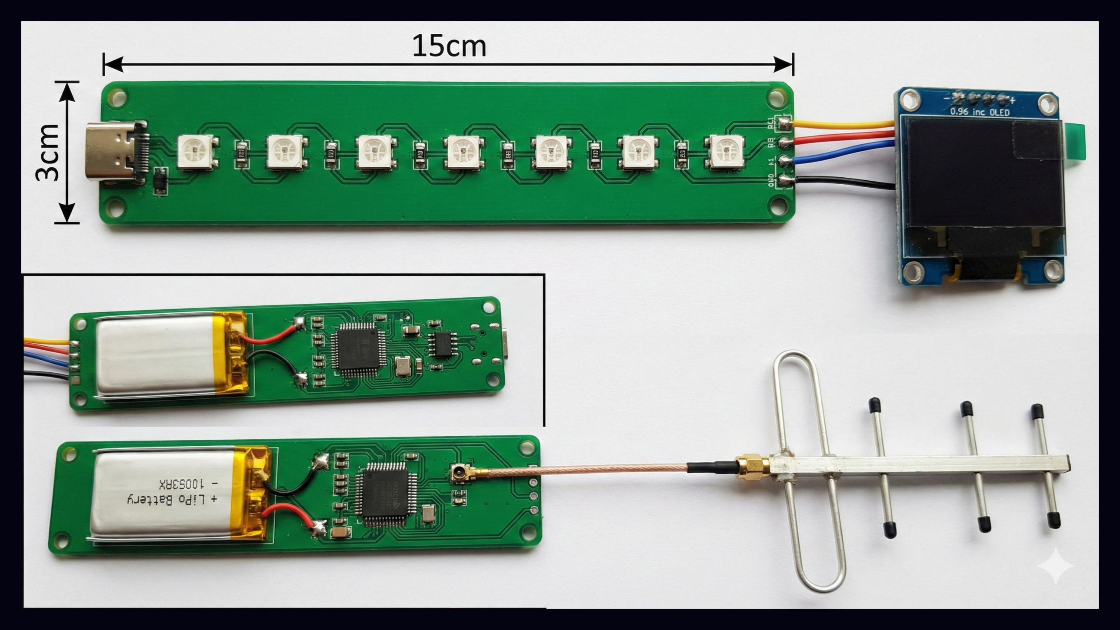
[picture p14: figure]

# dalszy plan

- 25.02.26 środa spotkanko 17:00 - pcb v1 i test antena
- 05.03.26 pcb final - zamówienie
- 25.03.26 spotkanko, zkładanie, lutowanie
- wrzesień - noc naukowców


██ pytania?

▒▒▒▒ cel - noc naukowców - wrzesień

▓▓▓ kalibracja

- przy resetcie?

░░░░░ animacje

- animacja jak się jest blisko do nadajnika - będzie karton, karton się otworzy i lis wyskoczy

██ rozłożenie zadań

- animacje/pixelizacja liska - Adrian - do 15.03.26
- pcb - v1 Kasia - do 25.02.26 - muszę podać plan pinów
- antena - Hubert + Antek - do 25.02.26 (blocked by order + druk (Max))
- programowanko - Adrian i Max - bez stanu bateri do 15.03.26 - dodanie stanu bateri do 30.03.26
- story - Antek
- obudowa - Antek3D (blocked by pcb (Kasia))

██ plan prezentacji

- Hubert - targi hobby
- Max - zakułucanie się nadajników
- Adrian - animacje/interfejs ekranu

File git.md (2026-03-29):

### Github

---

1. __Pobieranie zmian__
    - `git fetch`
    - `git pull`

---

2. __Wrzucenie wszystkich zmian__
    - `git add .`

    Lub wybrany folder/plik
    - `git add .\pcb\`

---

3. __Status__
    `git status`

---

4. __Commit__
    `git commit -m` __"wiadomość"__

---

5. __Push__
    `git push`

    Jeżeli nie przejdzie to:
    `git push origin main`

6. __Merge__
    1. `git add .` `git commit -m "moje zmiany"`
    
    2. `git fetch`
    
    3. `git merge origin/main`
    
    4. Rozwiązać konflikty
    
    5. `git push origin main --force-with-lease`

---

7. __Revert__
    1. Znależć hash commita np: `3cdeabb6d4475bf22c77ce93f576f29bd75ad27a`

    2. `git revert 3cdeabb6d4475bf22c77ce93f576f29bd75ad27a`

    3. Klikamy ESC a potem __:wq__ i enter. (VIM)

    4. `git push`

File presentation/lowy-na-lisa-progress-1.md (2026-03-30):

---
theme:
  override:
    code:
      alignment: left
      background: false
---

Coś działa
===

Moduły nrf905 działały odrazu po skonfigurowaniu przykładu z libki nrf905 na arduino, ale jeden kabel był podłączony w złym miejscu więc aż to działało mineły 2 dni.

Możemy spingować moduły, ale zawsze nam pokazują ten sam RTT bo różnica czasowa jest za mała by ją zarejestrować.

Niestety te moduły nie nadają się do naszych łowów...

<!-- end_slide -->

Nowe moduły!
===

<!-- column_layout: [1, 1] -->

<!-- column: 0 -->

# Doszły nam wczesniej

## nrf905

- działają, pingują się
- nie podają nam RSSI
- tylko działają na LoRa

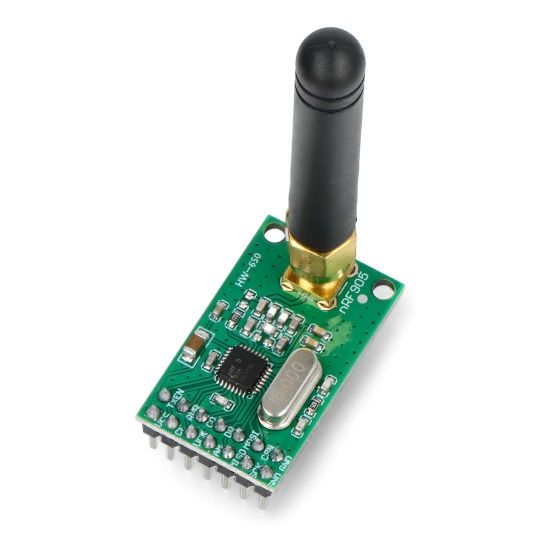
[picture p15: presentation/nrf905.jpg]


<!-- column: 1 -->

# Doszły nam pózniej

## HM-TRLR-D-TTL-868

- nie mamy jescze kodu dla nich
- mają różne modulacje - FSK, GFSK, LoRa
- powinny nam podawać moc odebranego sygnału
- miały przyjść wczesniej...

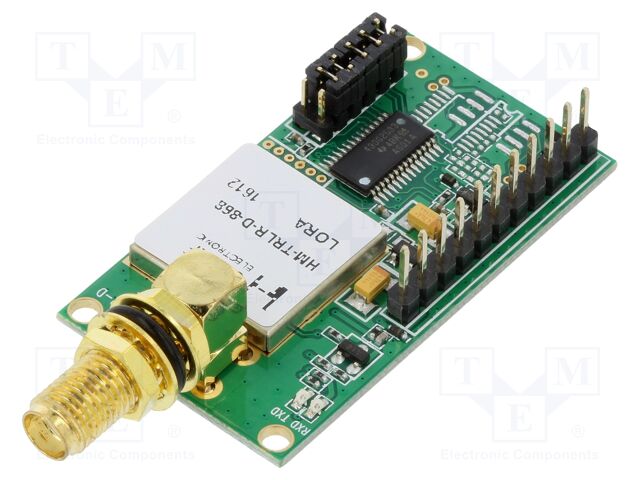
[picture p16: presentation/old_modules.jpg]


<!-- end_slide -->

Co teraz?
===

Zajmujemy się modułami HM-TRLR-D-TTL-868 i przepisujemy kod na te moduły.

Raczej powinniśmy się jescze zmieścic w terminie wczesniej założonym, skończyć pierwszą wersje przed końcem tego miesiąca.

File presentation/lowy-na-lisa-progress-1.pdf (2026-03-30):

# Coś działa

Moduły nrf905 działały odrazu po skonfigurowaniu przykładu z libki nrf905 na arduino, ale jeden kabel był podłączony w złym miejscu więc aż to działało mineły 2 dni.

Możemy spingować moduły, ale zawsze nam pokazują ten sam RTT bo różnica czasowa jest za mała by ją zarejestrować.

Niestety te moduły nie nadają się do naszych łowów...

# Nowe moduły!

██ Doszły nam wczesniej | ██ Doszły nam pózniej
▓▓▓ nrf905 | ▓▓▓ HM-TRLR-D-TTL-868
- działają, pingują się | • nie mamy jescze kodu dla nich
- nie podają nam RSSI | • mają różne modulacje - FSK,
- tylko działają na LoRa | GFSK, LoRa
| • powinny nam podawać moc
| odebranego sygnału
| • miały przyjść wczesniej...

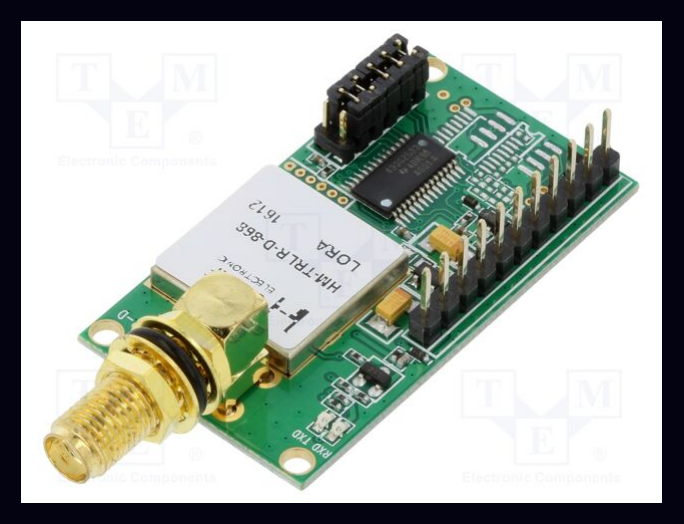
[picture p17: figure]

# Co teraz?

Zajmujemy się modułami HM-TRLR-D-TTL-868 i przepisujemy kod na te moduły.

Raczej powinniśmy się jescze zmieścic w terminie wczesniej założonym, skończyć pierwszą wersje przed końcem tego miesiąca.

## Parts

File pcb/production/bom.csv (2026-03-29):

Designator | Footprint | Quantity | Value | LCSC Part #
BT1 | PinHeader_1x02_P2.54mm_Vertical | 1 | 3.7V ~500mAh
C1, C10, C11, C16, C17, C18, C2, C3, C4, C8 | 0402 | 10 | 100n | C307331
C12, C5, C6, C7, C9 | 0603 | 5 | 10u | C19702
C13, C14, C15 | 0603 | 3 | 22u | C59461
D1, D2, D3, D4, D5, D6, D7 | LED_WS2812B_PLCC4_5.0x5.0mm_P3.2mm | 7 | WS2812B | C48586674
D8 | D_SOD-323 | 1 | B5819WS SL | C7420331
HTCC-AM1 | HTCC-AM01 | 1 | ~
J1 | PinHeader_1x04_P2.54mm_Vertical | 1 | Display
J3 | USB_C_Receptacle_G-Switch_GT-USB-7010ASV | 1 | USB_C_Receptacle_USB2.0_16P | C2988369
L1 | 1008 | 1 | 1uH (2-3A saturation) | C2849428
LDO1 | UDFN-4-1EP_1x1mm_P0.65mm_EP0.48x0.48mm | 1 | WL9005D4-33 | C5357206
Q1, Q2 | SOT-23 | 2 | AO3400A | C20917
R1 | 0603 | 1 | 2.4k | C22940
R10, R9 | 0402 | 2 | 1M | C26083
R2, R3 | 0603 | 2 | 5.1k | C23186
R4 | 0603 | 1 | 220k | C22961
R5 | 0402 | 1 | 470R | C25117
R6 | 0603 | 1 | 510k | C23192
R7 | 0603 | 1 | 100k | C25803
SW1, SW2, SW3, SW4 | SW_TS31-46-35-BK-B-160-RA-SMT-TR | 4 | TS24CA | C393942
U1 | Texas_RWU0007A_VQFN-7_2x2mm_P0.5mm | 1 | TPS61022 | C915088
U2 | SOT-23-5 | 1 | TP4054 | C32574
U3 | SOT-666 | 1 | USBLC6-2P6 | C2827693
U4 | SSOP-10-1EP_3.9x4.9mm_P1mm_EP2.1x3.3mm | 1 | CH340K | C968586

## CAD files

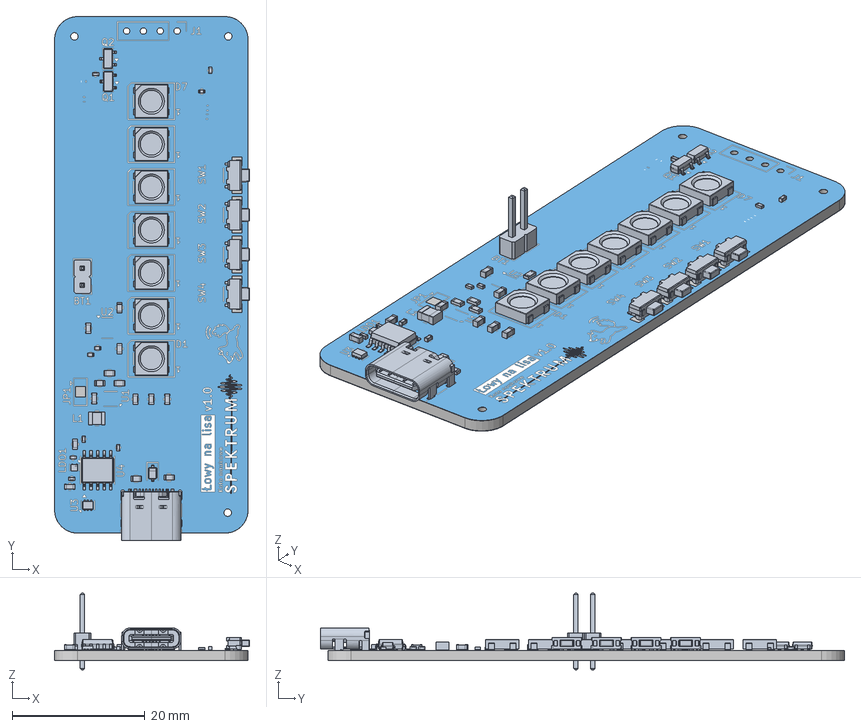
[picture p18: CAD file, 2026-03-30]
pcb/lowy-na-lisa.step
29.4 x 79.0 x 11.5 mm
SOT-23 x 2
TS31-46-35-BK-B-160-RA-SMT-TR x 4
R_0402_1005Metric x 3
C_0603_1608Metric x 8
R_0603_1608Metric x 6
LED_WS2812B_PLCC4_5.0x5.0mm_P3.2mm x 7
C_0402_1005Metric x 6
L_1008_2520Metric
PinHeader_1x02_P2.54mm_Vertical
USB_C_Receptacle_GCT_USB4105-xx-A_16P_TopMnt_Horizontal
SOT-666
D_SOD-323
UDFN-4-1EP_1x1mm_P0.65mm_EP0.48x0.48mm
SSOP-10-1EP_3.9x4.9mm_P1mm_EP2.1x3.3mm
lowy-na-lisa_silkscreen x 2
lowy-na-lisa_soldermask x 2
lowy-na-lisa_PCB

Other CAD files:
pcb/lowy-na-lisa.stl

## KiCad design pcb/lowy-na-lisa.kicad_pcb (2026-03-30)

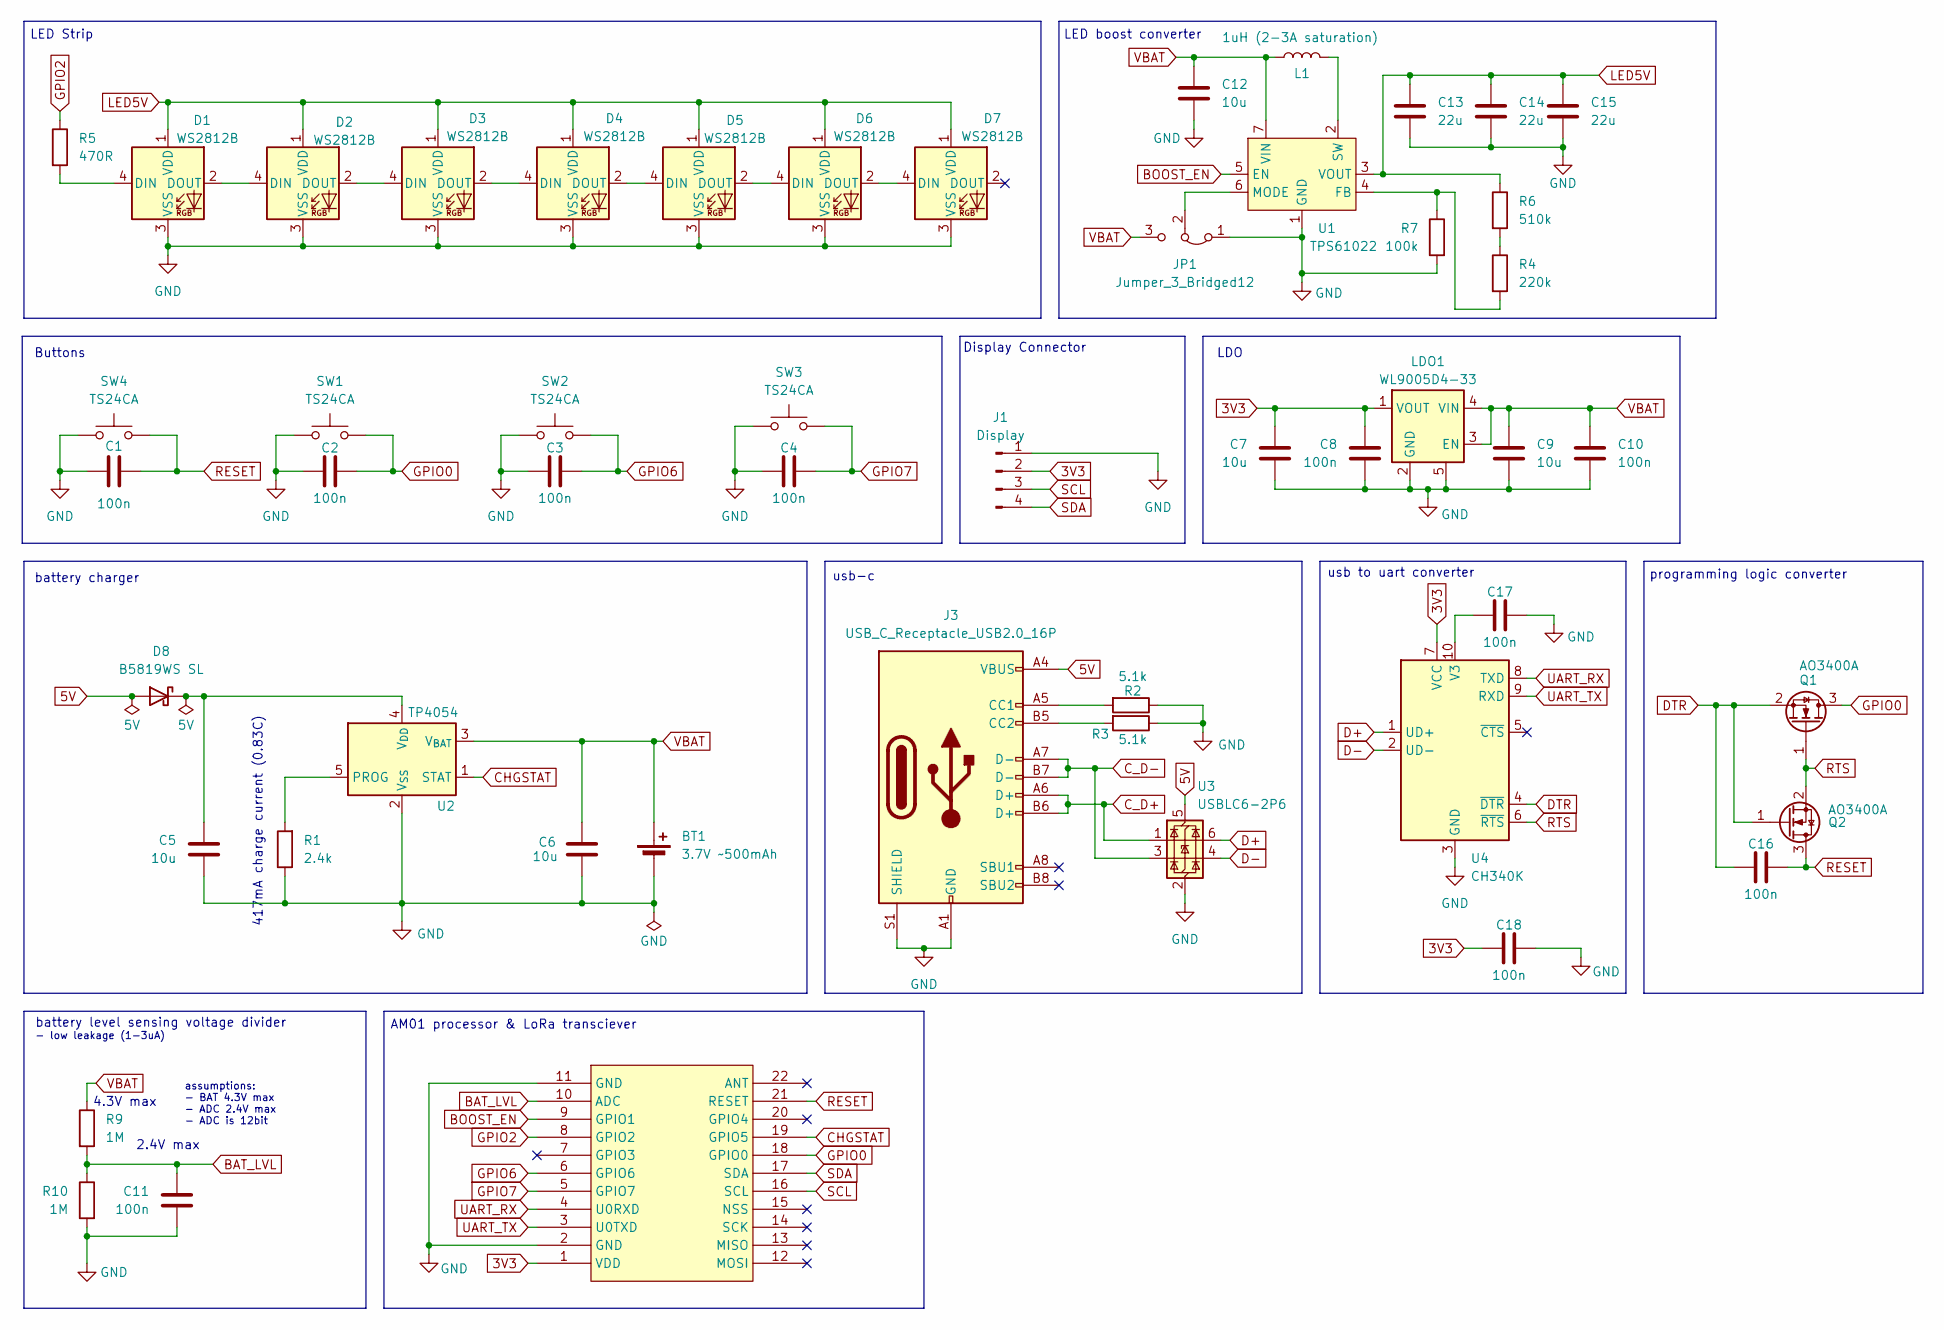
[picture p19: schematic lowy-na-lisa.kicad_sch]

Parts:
BT1: 3.7V ~500mAh; PinHeader_1x02_P2.54mm_Vertical
C1, C2, C3, C4, C8, C10, C11, C16, C17, C18: 100n; C_0402_1005Metric; LCSC C307331
C5, C6, C7, C9, C12: 10u; C_0603_1608Metric; LCSC C19702
C13, C14, C15: 22u; C_0603_1608Metric; LCSC C59461
D1, D2, D3, D4, D5, D6, D7: WS2812B; LED_WS2812B_PLCC4_5.0x5.0mm_P3.2mm; LCSC C48586674
D8: B5819WS SL; D_SOD-323; LCSC C7420331
HTCC-AM1: HTCC-AM01
J1: Display; PinHeader_1x04_P2.54mm_Vertical
J3: USB_C_Receptacle_USB2.0_16P; USB_C_Receptacle_G-Switch_GT-USB-7010ASV; LCSC C2988369
JP1: Jumper_3_Bridged12; SolderJumper-3_P1.3mm_Bridged2Bar12_Pad1.0x1.5mm
L1: 1uH (2-3A saturation); L_1008_2520Metric; LCSC C2849428
LDO1: WL9005D4-33; UDFN-4-1EP_1x1mm_P0.65mm_EP0.48x0.48mm; LCSC C5357206
Q1, Q2: AO3400A; SOT-23; LCSC C20917
R1: 2.4k; R_0603_1608Metric; LCSC C22940
R2, R3: 5.1k; R_0603_1608Metric; LCSC C23186
R4: 220k; R_0603_1608Metric; LCSC C22961
R5: 470R; R_0402_1005Metric; LCSC C25117
R6: 510k; R_0603_1608Metric; LCSC C23192
R7: 100k; R_0603_1608Metric; LCSC C25803
R9, R10: 1M; R_0402_1005Metric; LCSC C26083
SW1, SW2, SW3, SW4: TS24CA; SW_TS31-46-35-BK-B-160-RA-SMT-TR; LCSC C393942
U1: TPS61022; Texas_RWU0007A_VQFN-7_2x2mm_P0.5mm; LCSC C915088
U2: TP4054; SOT-23-5; LCSC C32574
U3: USBLC6-2P6; SOT-666; LCSC C2827693
U4: CH340K; SSOP-10-1EP_3.9x4.9mm_P1mm_EP2.1x3.3mm; LCSC C968586

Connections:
3V3: C7.1, C8.1, C18.1, HTCC-AM1.1 (VDD), J1.2, LDO1.1 (VOUT), U4.7 (VCC)
5V: D8.2 (A), J3.A4 (VBUS), J3.A9 (VBUS), J3.B4 (VBUS), J3.B9 (VBUS), U3.5 (VBUS)
BAT_LVL: C11.1, HTCC-AM1.10 (ADC), R9.2, R10.1
BOOST_EN: HTCC-AM1.9 (GPIO1), U1.5 (EN)
CHGSTAT: HTCC-AM1.19 (GPIO5), U2.1 (STAT)
C_D+: J3.A6 (D+), J3.B6 (D+), U3.1 (I/O1)
C_D-: J3.A7 (D-), J3.B7 (D-), U3.3 (I/O2)
D+: U3.6 (I/O1), U4.1 (UD+)
D-: U3.4 (I/O2), U4.2 (UD-)
DTR: C16.1, Q1.2 (S), Q2.1 (G), U4.4 (~DTR)
GND: BT1.2 (-), C1.1, C2.1, C3.1, C4.1, C5.2, C6.1, C7.2, C8.2, C9.2, C10.2, C11.2, C12.2, C13.2, C14.2, C15.2, C17.2, C18.2, D1.3 (VSS), D2.3 (VSS), D3.3 (VSS), D4.3 (VSS), D5.3 (VSS), D6.3 (VSS), D7.3 (VSS), HTCC-AM1.2 (GND), HTCC-AM1.11 (GND), J1.1, J3.A1 (GND), J3.A12 (GND), J3.B1 (GND), J3.B12 (GND), J3.S1 (SHIELD), JP1.1 (A), LDO1.2 (GND), LDO1.5, R1.1, R2.1, R3.1, R7.2, R10.2, SW1.1, SW2.1, SW3.1, SW4.1, U1.1 (GND), U2.2 (V_{SS}), U3.2 (GND), U4.3 (GND), U4.11 (GND)
GPIO0: C2.2, HTCC-AM1.18 (GPIO0), Q1.3 (D), SW1.2
GPIO2: HTCC-AM1.8 (GPIO2), R5.1
GPIO6: C3.2, HTCC-AM1.6 (GPIO6), SW2.2
GPIO7: C4.2, HTCC-AM1.5 (GPIO7), SW3.2
LED5V: C13.1, C14.1, C15.1, D1.1 (VDD), D2.1 (VDD), D3.1 (VDD), D4.1 (VDD), D5.1 (VDD), D6.1 (VDD), D7.1 (VDD), R6.1, U1.3 (VOUT)
unnamed: D1.4 (DIN), R5.2
unnamed: D1.2 (DOUT), D2.4 (DIN)
unnamed: D2.2 (DOUT), D3.4 (DIN)
unnamed: D3.2 (DOUT), D4.4 (DIN)
unnamed: D4.2 (DOUT), D5.4 (DIN)
unnamed: D5.2 (DOUT), D6.4 (DIN)
unnamed: D6.2 (DOUT), D7.4 (DIN)
unnamed: C5.1, D8.1 (K), U2.4 (V_{DD})
unnamed: J3.A5 (CC1), R2.2
unnamed: J3.B5 (CC2), R3.2
unnamed: JP1.2 (C), U1.6 (MODE)
unnamed: R4.1, R6.2
unnamed: R4.2, R7.1, U1.4 (FB)
unnamed: L1.2, U1.2 (SW)
unnamed: R1.2, U2.5 (PROG)
unnamed: C17.1, U4.10 (V3)
RESET: C1.2, C16.2, HTCC-AM1.21 (RESET), Q2.3 (D), SW4.2
RTS: Q1.1 (G), Q2.2 (S), U4.6 (~RTS)
SCL: HTCC-AM1.16 (SCL), J1.3
SDA: HTCC-AM1.17 (SDA), J1.4
UART_RX: HTCC-AM1.4 (U0RXD), U4.8 (TXD)
UART_TX: HTCC-AM1.3 (U0TXD), U4.9 (RXD)
VBAT: BT1.1 (+), C6.2, C9.1, C10.1, C12.1, JP1.3 (B), L1.1, LDO1.3 (EN), LDO1.4 (VIN), R9.1, U1.7 (VIN), U2.3 (V_{BAT})

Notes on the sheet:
usb to uart converter
LED Strip
LDO
Buttons
2.4V max
- low leakage (1-3uA)
programming logic converter
assumptions: - BAT 4.3V max - ADC 2.4V max - ADC is 12bit
battery level sensing voltage divider
LED boost converter
usb-c
417mA charge current (0.83C)
Display Connector
4.3V max
AM01 processor & LoRa transciever
battery charger

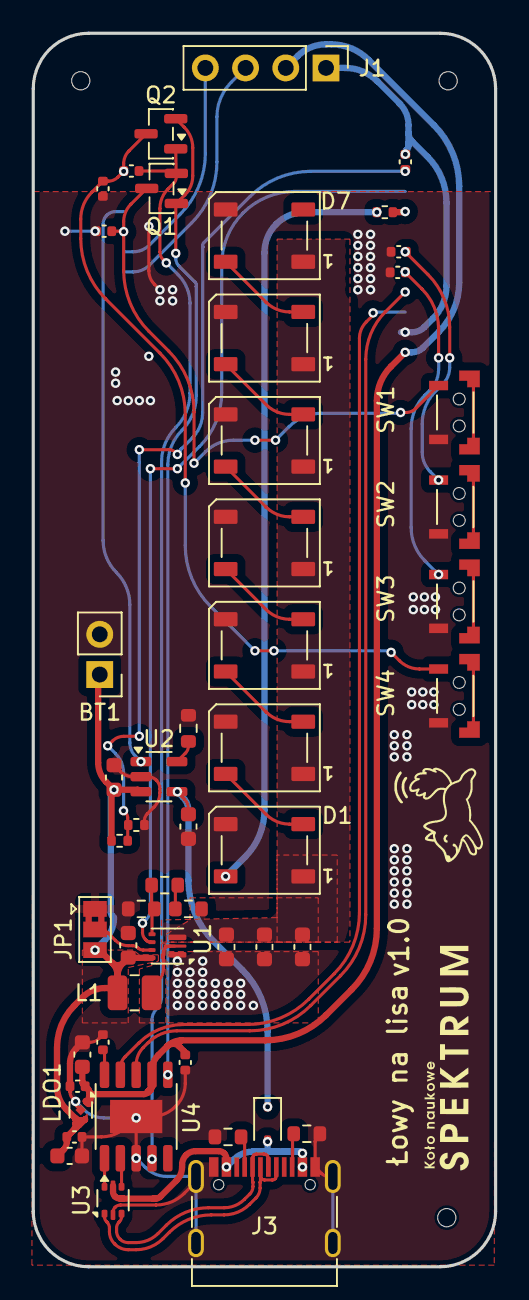
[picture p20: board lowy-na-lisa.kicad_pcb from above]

Board: 2 copper layers, 29.2 x 77.9 mm, 52 parts (1 on the bottom side), 39 nets.

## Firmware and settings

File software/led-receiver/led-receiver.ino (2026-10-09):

// Plain-LED receiver: ESP32 + Seeed LoRa-E5 (STM32WLE5JC, AT-command firmware,
// https://wiki.seeedstudio.com/LoRa-E5_STM32WLE5JC_Module/) over UART2, wired
// as a drop-in stand-in for receiver.ino's CubeCell+HM-TRLR+NeoPixel setup.
// Mirrors receiver.ino's constants, transmitter-id/channel scheme, packet
// validation, RSSI display and log strings as closely as the hardware allows:
//   - Radio: SX126x on CubeCell -> LoRa-E5 in AT+TEST P2P mode. Same
//     frequency scheme (BASE_RF_FREQUENCY + (id-1)*FREQUENCY_STEP), SF7,
//     125 kHz BW, preamble 8. The LoRa-E5's AT set has no sync-word register,
//     so the sync_word[CAFE<id>x4BABE] filtering receiver.ino does at the
//     radio is replicated here at the application layer instead: payload[0]
//     and payload[1] must both equal the configured transmitter id.
//   - Display: 7 CubeCell NeoPixels -> 7 plain LEDs on LED_PINS[], driven
//     with the same to_first_led_bits/to_last_led_bits/display_bits_on_leds
//     bit math as receiver.ino, just digitalWrite instead of NeoPixel colors.
//   - Id cycling: receiver.ino changes id on a SW1 press; here it's a button
//     wired to GPIO32 (to GND, internal pull-up), short-press only - no
//     long-press power-off, since this board has no equivalent sleep mode. A digit
//     1-N over USB serial does the same thing (N = channel setting, default 7).
//
// Wiring: ESP32 TX2 (GPIO17) -> LoRa-E5 RX, ESP32 RX2 (GPIO16) <- LoRa-E5 TX,
// GND-GND. LEDs on LED_PINS[] (D33,D25,D26,D27,D14,D12,D13, reversed from the
// original D13,D12,D14,D27,D26,D25,D33 wiring), each with a series resistor
// to GND (active-HIGH).
#include <Arduino.h>
#include <Preferences.h>
#include <LisekOta.h>  // updates and version readout over Bluetooth, software/libraries

#define MODULE_RX 16  // ESP32 RX2 <- LoRa-E5 TX
#define MODULE_TX 17  // ESP32 TX2 -> LoRa-E5 RX
#define MODULE_BAUD 9600  // LoRa-E5 default AT baud

// Same constants as receiver.ino.
#define BASE_RF_FREQUENCY_HZ 863000000UL
#define FREQUENCY_STEP_HZ 500000UL
#define RF_SF "SF7"        // LORA_SPREADING_FACTOR 7
#define RF_BW "125"        // LORA_BANDWIDTH 0 -> 125 kHz
#define RF_PREAMBLE 8       // LORA_PREAMBLE_LENGTH
#define RF_POWER 14         // TX_OUTPUT_POWER (RX side power is unused but AT+TEST=RFCFG sets both)

const int LED_PINS[] = { 33, 25, 26, 27, 14, 12, 13 };  // reversed order
const int NUM_LEDS = sizeof(LED_PINS) / sizeof(LED_PINS[0]);

// No packet from the selected transmitter for this long = no signal, LEDs off
// (it sends every 100 ms).
#define NO_SIGNAL_MS 1000

#define BUTTON_PIN 32  // external button to GND, matches receiver.ino's SW1 (GPIO0 on CubeCell)

uint8_t transmitter_id = 1;  // matches receiver.ino's initial set_transmitter_id(1)

// Panel settings (web page over Bluetooth only, stored in NVS so they survive
// power-off):
//   leds: how the selected id is shown
//     unary (default): that many LEDs from LED7 down, so at most 7
//     binary: LED7 = 1, LED6 = 2, LED5 = 4, LED4 = 8, up to 9
//   channels: how many transmitter ids the button cycles through (default 7)
volatile bool binary_leds = false;
volatile uint8_t channels = 7;
volatile bool settings_changed = false;
volatile uint8_t requested_id = 0;  // applied by loop(), which owns the radio UART
volatile bool requested_id_ok = false;
SemaphoreHandle_t id_change_done;

uint8_t max_id() {
  uint8_t shown = binary_leds ? 9 : 7;
  return channels < shown ? channels : shown;
}

void advertise_settings() {
  LisekOta::setUserBits((binary_leds ? 1 : 0) | ((channels - 1) << 1));
}

String lastLine;

// Reads one line from the module, trims it, times out after ms.
String readLine(uint32_t timeoutMs) {
  uint32_t start = millis();
  String line;
  while (millis() - start < timeoutMs) {
    while (Serial1.available()) {
      char c = Serial1.read();
      if (c == '\n') {
        line.trim();
        if (line.length()) return line;
      } else if (c != '\r') {
        line += c;
      }
    }
  }
  line.trim();
  return line;
}

// Sends an AT command, returns the first non-empty response line.
String sendAT(const String &cmd, uint32_t timeoutMs = 1000) {
  while (Serial1.available()) Serial1.read();
  Serial1.print(cmd);
  Serial1.print("\r\n");
  String r = readLine(timeoutMs);
  lastLine = r;
  return r;
}

// --- LED bit helpers, ported 1:1 from receiver.ino ---

uint8_t to_last_led_bits(uint8_t x) {
  if (x >= 8) return 0xFF;
  return ((1u << x) - 1u);
}

uint8_t to_first_led_bits(uint8_t x) {
  if (x == 0) return 0;
  if (x >= 8) return 0xFF;
  x += 1;
  return ((1u << x) - 1u) << (8 - x);
}

void display_bits_on_leds(int8_t bits) {
  for (int i = 0; i < NUM_LEDS; i++) {
    digitalWrite(LED_PINS[i], (bits & (1 << i)) > 0 ? HIGH : LOW);
  }
}

void display_strength_on_leds(int8_t strength) {
  display_bits_on_leds(to_last_led_bits(strength));
}

uint8_t id_bits(uint8_t id) {
  if (!binary_leds) return to_first_led_bits(id);
  uint8_t bits = 0;
  for (int b = 0; b < 4; b++)
    if (id & (1 << b)) bits |= 1 << (NUM_LEDS - 1 - b);
  return bits;
}

// "set leds=binary|unary" / "set channels=N" from the web panel (runs on the
// Bluetooth task).
bool on_setting(const String &key, const String &value) {
  Preferences prefs;
  if (key == "id") {
    int id = value.toInt();
    if (value != String(id) || id < 1 || id > max_id()) return false;
    while (xSemaphoreTake(id_change_done, 0) == pdTRUE) {}
    requested_id = id;
    requested_id_ok = false;
    settings_changed = true;
    if (xSemaphoreTake(id_change_done, pdMS_TO_TICKS(4000)) != pdTRUE || !requested_id_ok) return false;
    prefs.begin("receiver", false);
    prefs.putUChar("id", id);
    prefs.end();
    return true;
  } else if (key == "leds" && (value == "binary" || value == "unary")) {
    binary_leds = value == "binary";
    prefs.begin("receiver", false);
    prefs.putBool("binary_leds", binary_leds);
  } else if (key == "channels" && value.toInt() >= 1 && value.toInt() <= (binary_leds ? 9 : 7)) {
    channels = value.toInt();
    prefs.begin("receiver", false);
    prefs.putUChar("channels", channels);
  } else {
    return false;
  }
  prefs.end();
  advertise_settings();
  settings_changed = true;
  return true;
}

// --- Radio setup, ported from receiver.ino's set_transmitter_id/SetChannel ---

// Sends a command line to the module, dropping anything still buffered.
void command(const char *cmd) {
  while (Serial1.available()) Serial1.read();
  Serial1.print(cmd);
  Serial1.print("\r\n");
}

// Reads module lines until one starts with `prefix` (other lines, e.g. a
// packet that was still in flight, are dropped). Returns as soon as it arrives.
bool waitFor(const char *prefix, uint32_t timeoutMs) {
  uint32_t start = millis();
  while (millis() - start < timeoutMs) {
    String l = readLine(timeoutMs - (millis() - start));
    if (l.startsWith(prefix)) return true;
  }
  return false;
}

// Sets the frequency for `id` and starts continuous receive. Every step moves
// on as soon as the module confirms it.
bool tune_and_receive(uint8_t id) {
  unsigned long freqHz = BASE_RF_FREQUENCY_HZ + (unsigned long)(id - 1) * FREQUENCY_STEP_HZ;
  char cfg[64];
  snprintf(cfg, sizeof cfg, "AT+TEST=RFCFG,%lu.%lu,%s,%s,%d,%d,%d,ON,OFF,OFF", freqHz / 1000000UL,
           (freqHz % 1000000UL) / 100000UL, RF_SF, RF_BW, RF_PREAMBLE, RF_POWER, RF_POWER);
  command(cfg);
  if (!waitFor("+TEST: RFCFG", 500)) return false;
  command("AT+TEST=RXLRPKT");
  if (!waitFor("+TEST: RXLRPKT", 300)) return false;
  transmitter_id = id;
  LisekOta::setId(id);
  return true;
}

// Full radio init: enters AT+TEST P2P mode at the frequency for `id` and
// starts continuous packet receive. Equivalent to receiver.ino's
// set_transmitter_id() (channel part) + Radio.Rx(0). Used at boot and as a
// fallback when a quick retune fails.
bool set_transmitter_id(uint8_t id) {
  // If a previous RXLRPKT session is still streaming (e.g. right after an
  // ESP32-only reset that didn't touch the module), plain AT won't interrupt
  // it - the module needs an explicit stop first. Best-effort: ignore the
  // reply, drain whatever comes back, then retry AT until a clean "+AT: OK".
  sendAT("AT+TEST=STOP");
  delay(200);
  while (Serial1.available()) Serial1.read();

  String r;
  bool atOk = false;
  for (int attempt = 0; attempt < 15 && !atOk; attempt++) {
    r = sendAT("AT", 500);
    atOk = (r == "+AT: OK");
  }
  if (!atOk) {
    // Silence means no power or a broken TX/RX wire; garbage means a wrong baud rate.
    Serial.printf("radio: no \"+AT: OK\" from LoRa-E5 after 15 tries, last reply \"%s\" (%u chars)\r\n", r.c_str(),
                  r.length());
    return false;
  }

  r = sendAT("AT+MODE=TEST");
  if (r.indexOf("+MODE: TEST") < 0) {
    Serial.printf("radio: AT+MODE=TEST answered \"%s\"\r\n", r.c_str());
    return false;
  }

  return tune_and_receive(id);
}

// Quick channel change for a module that is already receiving in TEST mode:
// stop, set the new frequency, receive again.
bool retune(uint8_t id) {
  command("AT+TEST=STOP");
  if (!waitFor("+TEST: STOP", 300)) return false;
  return tune_and_receive(id);
}

// Parses "+TEST: LEN:2, RSSI:-42, SNR:9".
void parseLenLine(const String &line, int &len, int &rssi, int &snr) {
  int li = line.indexOf("LEN:");
  len = li >= 0 ? line.substring(li + 4).toInt() : 0;
  int ri = line.indexOf("RSSI:");
  rssi = ri >= 0 ? line.substring(ri + 5).toInt() : 0;
  int si = line.indexOf("SNR:");
  snr = si >= 0 ? line.substring(si + 4).toInt() : 0;
}

// Parses "+TEST: RX "0102"" -> raw bytes.
bool parseRxData(const String &line, uint8_t *out, int &outLen) {
  int q1 = line.indexOf('"');
  int q2 = line.lastIndexOf('"');
  if (q1 < 0 || q2 <= q1) return false;
  String hex = line.substring(q1 + 1, q2);
  outLen = 0;
  for (int i = 0; i + 1 < (int)hex.length() && outLen < 32; i += 2) {
    out[outLen++] = strtol(hex.substring(i, i + 2).c_str(), nullptr, 16);
  }
  return outLen > 0;
}

int pendingRssi = 0;
int pendingSnr = 0;
bool havePending = false;

void setup() {
  // 80 MHz is plenty (UART, LEDs, Bluetooth) and draws far less than 240 MHz,
  // which matters on battery: Bluetooth on top of 240 MHz browned the boards out.
  setCpuFrequencyMhz(80);
  Serial.begin(115200);
  Serial.println("Hej liski!");
  LisekOta::begin("receiver");
  id_change_done = xSemaphoreCreateBinary();
  Preferences prefs;
  prefs.begin("receiver", true);
  binary_leds = prefs.getBool("binary_leds", false);
  channels = constrain(prefs.getUChar("channels", 7), 1, binary_leds ? 9 : 7);
  transmitter_id = constrain(prefs.getUChar("id", 1), 1, min((int)channels, binary_leds ? 9 : 7));
  prefs.end();
  advertise_settings();
  Serial.println("firmware " LISEK_VERSION);

  pinMode(BUTTON_PIN, INPUT_PULLUP);
  for (int i = 0; i < NUM_LEDS; i++) pinMode(LED_PINS[i], OUTPUT);

  // Startup LED chase, ported from receiver.ino's boot animation.
  for (int rep = 0; rep < 2; rep++) {
    for (int j = 0; j < 7; j++) {
      display_bits_on_leds(to_first_led_bits(j));
      delay(50);
    }
    for (int j = 0; j < 7; j++) {
      display_bits_on_leds(to_last_led_bits(8 - j));
      delay(50);
    }
  }
  display_bits_on_leds(0);

  Serial1.begin(MODULE_BAUD, SERIAL_8N1, MODULE_RX, MODULE_TX);
  delay(200);

  while (!set_transmitter_id(transmitter_id)) {
    Serial.println("radio init failed, retrying in 2s...");
    delay(2000);
  }
  LisekOta::markHealthy();
  LisekOta::onSetting(on_setting);
  Serial.println("into RX mode");
}

// While non-zero, the LEDs show the newly selected id until this millis() time
// (receiver.ino's 500 ms id flash, without blocking presses or the radio).
uint32_t id_flash_until = 0;
// millis() of the last packet from the selected transmitter, 0 = none shown.
uint32_t last_packet_ms = 0;

bool change_transmitter_id_to(uint8_t id) {
  last_packet_ms = 0;  // the old transmitter's strength no longer applies
  // Feedback first: the id shows on the LEDs the moment the button goes down.
  display_bits_on_leds(id_bits(id));
  id_flash_until = millis() + 500;
  if (id_flash_until == 0) id_flash_until = 1;

  if (retune(id) || set_transmitter_id(id)) {
    Serial.printf("\r\nChanged transmitter id to %d\r\n", transmitter_id);
    return true;
  } else {
    Serial.println("failed to change transmitter id");
    return false;
  }
}

void loop() {
  static String line;

  // Button: short press cycles the transmitter id, same as receiver.ino's
  // SW1 - but no long-press power-off, this board has no sleep mode to match.
  // Acts on the press edge itself; contact bounce within 30 ms of the last
  // accepted edge is ignored instead of waited out.
  static bool buttonHigh = true;
  static uint32_t lastEdgeMs = 0;
  bool high = digitalRead(BUTTON_PIN) == HIGH;
  if (high != buttonHigh && millis() - lastEdgeMs >= 30) {
    buttonHigh = high;
    lastEdgeMs = millis();
    if (!high) change_transmitter_id_to(1 + (transmitter_id % max_id()));
  }

  // Settings changed from the panel: show the id the new way; an id that is no
  // longer allowed (fewer channels, 8+ in unary) goes back to 1.
  if (settings_changed) {
    settings_changed = false;
    uint8_t new_id = requested_id;
    requested_id = 0;
    if (new_id) {
      requested_id_ok = change_transmitter_id_to(new_id);
      xSemaphoreGive(id_change_done);
    } else if (transmitter_id > max_id()) {
      change_transmitter_id_to(1);
    } else {
      display_bits_on_leds(id_bits(transmitter_id));
      id_flash_until = millis() + 1500;
    }
  }

  if (id_flash_until && (int32_t)(millis() - id_flash_until) >= 0) {
    id_flash_until = 0;
    display_bits_on_leds(0);
  }

  // Signal lost: don't keep showing the last strength.
  if (last_packet_ms && millis() - last_packet_ms >= NO_SIGNAL_MS) {
    last_packet_ms = 0;
    if (!id_flash_until) display_bits_on_leds(0);
  }

  // A firmware update over Bluetooth fills the LEDs as it arrives.
  if (LisekOta::updating()) {
    uint32_t total, done = LisekOta::progress(&total);
    display_strength_on_leds(total ? 1 + done * 6 / total : 0);
  }

  // A digit over USB serial does the same thing.
  while (Serial.available()) {
    char c = Serial.read();
    if (c >= '1' && c <= '0' + max_id()) {
      change_transmitter_id_to(c - '0');
    }
  }

  while (Serial1.available()) {
    char c = Serial1.read();
    if (c == '\n') {
      line.trim();
      if (line.length()) {
        if (line.startsWith("+TEST: LEN:")) {
          int size, rssi, snr;
          parseLenLine(line, size, rssi, snr);

          if (size < 2) {
            Serial.println("WARN: packet of size 0 or 1 recieved");
          } else {
            // Actual payload arrives on the next "+TEST: RX ..." line; stash
            // rssi/snr for it.
            pendingRssi = rssi;
            pendingSnr = snr;
            havePending = true;
          }
        } else if (line.startsWith("+TEST: RX ") && havePending) {
          havePending = false;
          uint8_t payload[32];
          int size = 0;
          if (parseRxData(line, payload, size)) {
            if (size > 29) size = 29;

            // sync_word filtering, done in receiver.ino's radio by matching
            // sync_word[2..5]==id; done here at the application layer.
            if (payload[0] != transmitter_id || payload[1] != transmitter_id) {
              // not our transmitter - ignore, matching receiver.ino's silent drop.
            } else {
              char rxpacket[30];
              memcpy(rxpacket, payload, size);
              rxpacket[size] = '\0';

              last_packet_ms = millis();
              if (!id_flash_until && !LisekOta::updating()) display_strength_on_leds((110 + pendingRssi) / (110 / 7));
              Serial.printf("received packet \"%s\" with rssi=%d snr=%d length=%d packet_tx_id=%d\r\n", rxpacket,
                            pendingRssi, pendingSnr, size, rxpacket[1]);
            }
          }
        } else if (line.length()) {
          Serial.printf("module: %s\r\n", line.c_str());
        }
      }
      line = "";
    } else if (c != '\r') {
      line += c;
    }
  }
}

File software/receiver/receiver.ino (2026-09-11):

#include "LoRaWan_APP.h"
#include "sx126x.h"
#include "Arduino.h"
#include "CubeCell_NeoPixel.h"
#include <Wire.h>
#include "HT_SSD1306Wire.h" 



#define BASE_RF_FREQUENCY 863000000  // Hz
#define FREQUENCY_STEP 500000

#define TX_OUTPUT_POWER 14  // dBm

#define LORA_BANDWIDTH 0         // [0: 125 kHz, \
                                 //  1: 250 kHz, \
                                 //  2: 500 kHz, \
                                 //  3: Reserved]
#define LORA_SPREADING_FACTOR 7  // [SF7..SF12]
#define LORA_CODINGRATE 1        // [1: 4/5, \
                                 //  2: 4/6, \
                                 //  3: 4/7, \
                                 //  4: 4/8]
#define LORA_PREAMBLE_LENGTH 8   // Same for Tx and Rx
#define LORA_SYMBOL_TIMEOUT 0    // Symbols
#define LORA_FIX_LENGTH_PAYLOAD_ON false
#define LORA_IQ_INVERSION_ON false


#define RX_TIMEOUT_VALUE 1000
#define BUFFER_SIZE 30  // Define the payload size here

#define LED_BOOST_ON GPIO1
#define LED_DATA GPIO2
#define SW1 GPIO0
#define SW2 GPIO6
#define SW3 GPIO7
#define BAT_LVL ADC

SSD1306Wire  display(0x3c, 500000, SDA, SCL, GEOMETRY_128_64, NULL); // addr , freq , SDA, SCL, resolution , rst
CubeCell_NeoPixel pixels(7, LED_DATA, NEO_GRB + NEO_KHZ800);



char txpacket[BUFFER_SIZE];
char rxpacket[BUFFER_SIZE];

static RadioEvents_t RadioEvents;
static TimerEvent_t sleep;

int16_t rssi, rxSize;

bool lora_idle = true;
bool powered_on = false;

uint8_t sync_word[8] = { 0xCA, 0xFE, 0x00, 0x00, 0x00, 0x00, 0xBA, 0xBE };


void setup() {
  Serial.begin(115200);
  Serial.println("Hej liski!");

  pinMode(SW1, INPUT_PULLUP);

  pinMode(LED_BOOST_ON,OUTPUT);
  digitalWrite(LED_BOOST_ON,HIGH);
  pixels.begin();
  pixels.clear();

  for (int i = 0; i < 2; i++) {
    for (int j = 0; j < 7; j++) {
      display_bits_on_leds(to_first_led_bits(j));
      delay(50);
    }
    for (int j = 0; j < 7; j++) {
      display_bits_on_leds(to_last_led_bits(8 - j));
      delay(50);
    }
  }
  // Show initial display buffer contents on the screen --
  // the library initializes this with an Adafruit splash screen.
  display.display();
  delay(2000); // Pause for 2 seconds

  // Clear the buffer
  display.clear();

  // Draw a single pixel in white
  display.setPixel(10, 10);

  // Show the display buffer on the screen. You MUST call display() after
  // drawing commands to make them visible on screen!
  display.display();

  display_bits_on_leds(0);

  rssi = 0;

  RadioEvents.RxDone = on_rx_done;
  Radio.Init(&RadioEvents);
  Radio.SetChannel(BASE_RF_FREQUENCY);



  Radio.SetRxConfig(MODEM_LORA, LORA_BANDWIDTH, LORA_SPREADING_FACTOR,
                    LORA_CODINGRATE, 0, LORA_PREAMBLE_LENGTH,
                    LORA_SYMBOL_TIMEOUT, LORA_FIX_LENGTH_PAYLOAD_ON,
                    0, true, 0, 0, LORA_IQ_INVERSION_ON, true);

  set_transmitter_id(1);
}


void loop() {
  if (powered_on && digitalRead(SW1) == LOW) {
    detachInterrupt(SW1);
    handle_button_press();
  }

  if (!powered_on) {
    
    sx126xSleep();
    while (digitalRead(SW1) == LOW)
      ;
    delay(50); // debounce
    attachInterrupt(SW1, on_wake, FALLING);
    Serial.println();
    Serial.flush();
    lowPowerHandler();
  }

  if (powered_on && lora_idle) {
    lora_idle = false;
    Serial.println("into RX mode");
    Radio.Rx(0);
  }
}

void on_rx_done(uint8_t *payload, uint16_t size, int16_t rssi, int8_t snr) {
  if (size < 2) {
    Serial.println("WARN: packet of size 0 or 1 recieved");
    Radio.Sleep();
    lora_idle = true;
    return;
  }

  if ((payload[0] != get_transmitter_id()) || (payload[1] != get_transmitter_id())) {
    Radio.Sleep();
    lora_idle = true;
    return;
  }

  if (size > 29)
    size = 29;

  memcpy(rxpacket, payload, size);
  rxpacket[size] = '\0';

  rssi = rssi;
  rxSize = size;
  display_strength_on_leds((110 + rssi) / (110 / 7));
  Serial.printf("received packet \"%s\" with rssi=%d snr=%d length=%d packet_tx_id=%d\r\n", rxpacket, rssi, snr, rxSize, rxpacket[1]);


  Radio.Sleep();
  lora_idle = true;
}

void handle_button_press() {
  int press_start = millis();
  delay(50);  // debounce
  if (digitalRead(SW1) == LOW) {
    int i = 1;
    
    while (digitalRead(SW1) == LOW) {
      if (millis() - press_start > 2500) {  // if pressed for longer than 2.5 seconds
        powered_on = false;
        i = (i + 1) % 8;
        display_bits_on_leds(1 << i);
        delay(30);
      }

      delay(5);
    };

    if (!powered_on) {
      display_bits_on_leds(0);
      Serial.println("powered off");
      for (int j = 0; j < 8; j++) {
        display_bits_on_leds(to_first_led_bits((7-j)));
        delay(300);
      }
      return;
    }

    set_transmitter_id(1 + (get_transmitter_id() % 6));
    Serial.printf("\r\nChanged transmitter id to %d\r\n", get_transmitter_id());

    Radio.Sleep();
    lora_idle = true;

    display_bits_on_leds(to_first_led_bits(get_transmitter_id()));
    delay(500);
    display_bits_on_leds(0);
  }
}

void on_wake() {
  if (!powered_on) {
    powered_on = true;

    Serial.println("woke up!");
    while (digitalRead(SW1) == LOW)
      ;
  }
}

void set_transmitter_id(uint8_t id) {
  for (int i = 0; i < 4; i++) {
    sync_word[i + 2] = id;
  }

  SX126xSetSyncWord(sync_word);
  Radio.SetChannel(BASE_RF_FREQUENCY+(id-1)*FREQUENCY_STEP);
}

uint8_t get_transmitter_id() {
  return sync_word[2];
}

void display_bits_on_leds(int8_t bits) {
  for (int i = 0; i < 7; i++) {
    uint32_t color;

    if ((bits & (1 << i)) > 0) {
      color = pixels.Color(20, 20, 20);
    }else {
      color = pixels.Color(0, 0, 0);
    }
    
    pixels.setPixelColor(i, color);
  }
  pixels.show();
}

uint8_t to_last_led_bits(uint8_t x) {
  if (x >= 8) return 0xFF;
  return ((1u << x) - 1u);
}

uint8_t to_first_led_bits(uint8_t x) {
  if (x == 0) return 0;
  if (x >= 8) return 0xFF;
  x += 1;
  return ((1u << x) - 1u) << (8 - x);
}

void display_strength_on_leds(int8_t strength) {
  display_bits_on_leds(to_last_led_bits(strength));
}

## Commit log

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2026-03-10 add pcb
    [plytka.kicad_pcb, plytka.kicad_sch]
2026-03-10 pcb update
    [plytka.kicad_pcb]
2026-03-12 pcb: add TPS61022 boost converter and simplify battery monitoring
    - Add TPS61022 boost converter
    - Simplify battery voltage sensing by removing DIVFET1 switched divider
    - Update voltage divider values, now 1M and 1M + cap for stabilizing
    - Add mode selection jumper for PFM/PWM switching
    - Update battery capacity to ~500mAh
    [plytka.kicad_pcb, plytka.kicad_sch]
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2026-03-14 aktualna wersja
    [plytka.kicad_pcb, plytka.kicad_sch]
2026-03-15 fix lineendings
    [plytka.kicad_sch]
2026-03-28 almost finish pcb
    [plytka.kicad_pcb, plytka.kicad_sch]
2026-03-28 smol fixy
    [plytka.kicad_pcb]
2026-03-29 nonchalant zaokronglenia
    [plytka.kicad_pcb]
2026-03-29 final final final??
    [plytka.kicad_pcb, plytka.kicad_sch]
2026-03-29 add production files to git
    [bom.csv, designators.csv, positions.csv]
2026-03-30 pcb: rename project, final touches, cleanup
    [lowy-na-lisa.kicad_pcb, lowy-na-lisa.kicad_sch]
2026-03-30 export 3d models as step
    [lowy-na-lisa.step]
2026-03-30 embed stl model in readme
    [lowy-na-lisa.stl]
2026-10-09 add ESP32 transmitter and LED receiver docs with Fritzing wiring
    - led-receiver: ESP32 + Seeed LoRa-E5 receiver sketch, README and Fritzing
    wiring (LEDs, button, LiPo + USB-C charger/boost, power switch)
    - fox-transmitter: sketch, README with channel/jumper table and programming
    steps, Fritzing wiring (WeMos D1 R32, 5x AA pack, HM-TRLR-D with SMA port)
    - fritzing-lib: generator helpers shared by both diagrams
    - README: Wersje index with expandable diagrams and connection tables
    [fox-transmitter.fzz, led-receiver.fzz]
2026-10-09 led-receiver diagram: power chain left of the ESP32, LEDs up a row, button under the LEDs, 3V3 along the board edge
    [led-receiver.fzz]
2026-10-09 led-receiver diagram: battery, charger and switch beside the ESP32 on its left
    [led-receiver.fzz]
2026-10-09 led-receiver diagram: LED4 wire straight, button within board height, battery above the charger with leads down
    [led-receiver.fzz]
2026-10-09 led-receiver: instant channel switching; diagram: charger at the bottom, small LiPo above it
    Channel changes took ~880 ms of fixed waits and repeated init (STOP + 200 ms,
    AT retries, MODE=TEST, RFCFG + 300 ms) plus a blocking 500 ms LED flash, and
    the button handler waited out debounce and release. Now the id shows on the
    LEDs on the press edge, the radio retunes with STOP -> RFCFG -> RXLRPKT, each
    step returning on the module's confirmation (~390 ms measured, was ~880 ms
    before the flash even started), and the flash no longer blocks. Full init
    remains for boot and as a fallback.
    [led-receiver.fzz]
2026-10-09 led-receiver diagram: battery off to the side, 5V/GND runs hug the top of the board
    [led-receiver.fzz]
2026-10-09 led-receiver diagram: battery in line with the charger so it doesn't widen the image
    [led-receiver.fzz]
2026-10-09 fox-transmitter diagram: power wires stay within the height of the board and cells
    [fox-transmitter.fzz]
2026-10-09 Bluetooth fleet view and signed OTA updates with rollback; receiver LEDs off when the signal is lost
    Both ESP32 sketches advertise role, channel id, state and firmware version over
    BLE and accept updates signed with the project key (ECDSA P-256). A new image
    stays only after the web page confirms it and the radio module answered;
    otherwise the bootloader rolls back. Web page (Chromium, KN Spektrum style)
    shows which devices are on and updates them in parallel. min_spiffs partition
    table, first install over USB via software/ota/usb-flash.sh.
2026-10-09 Channels 1-8 with a binary LED mode switched from the fleet panel; browser support notes
    Receiver: ids 1-7 shown as before, or 1-8 in binary (LED7 = 1 ... LED4 = 8).
    The mode is stored in NVS and only changes via 'set leds=...' from the web
    panel, behind a confirmation. Fleet page polls added devices every 30 s where
    advertisement watching is unavailable (no flag, Linux, ChromeOS). Docs: id 7
    and 8 in the channel and jumper tables.
2026-10-09 Fleet panel for phones, receiver channel count, hidden transmitters, faster BLE updates
    - Receiver: number of channels (default 7, up to 8 in binary LED mode) set from
    the panel, stored in NVS.
    - Transmitter: Bluetooth goes quiet 10 min after power-on by default (panel:
    10/30/60 min or always visible), so phones cannot find the fox by its signal.
    - Updates: writes without response with an 8 KiB ack window and a 7.5-15 ms
    connection interval; older firmware falls back to acknowledged writes.
    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
2026-10-09 Łowy na Lisa panel: dashboard layout with filters, search and device cards; Inter
    Status strip doubles as filters, search by name/channel/version, cards with
    type icon and colour (red transmitter, blue receiver), status pill and icon
    actions; GitHub and open-source links. Inter 4.1 subset to Latin/Polish is
    bundled (OFL) so the page works offline. Acknowledged-write fallback for
    firmware without the fast path no longer waits for 8 KiB acks.
    Verified on hardware: update over BLE from 56302f2 to 951c29a on a D1 R32
    transmitter (214 s on the old acknowledged path), pending with rollback
    countdown after reboot, confirmed, running from app1.
    [ble_test.py]
2026-10-09 Panel: floating top pills, no-flags test harness, flow-control fix; foxes never hide by default
    - Fix: a notification could clear the transfer's wake-up right after the check
    re-armed it, stalling an update until the 20 s timeout (found with the mock).
    - test/: fake Web Bluetooth with Chrome's no-flags surface (picker + GATT only),
    old and new firmware protocols; three parallel updates pass in 13 s.
    - Scan button only on macOS/Android, where Chrome implements requestLEScan;
    'globally disabled' (Linux without flag, Brave) explains how to enable it.
    - Transmitters keep Bluetooth on unless hiding is set in the panel.
    - Floating, fully rounded logo and GitHub/open-source pills.
    [fox-transmitter.ino]
2026-10-09 Module registry and USB auto-flash
    software/ota/usb-autoflash.sh watches for boards on USB, picks the firmware by
    the registered MAC or else the USB-serial chip (CP2102 = receiver DevKit,
    CH340 = D1 R32 transmitter), flashes it, checks in the boot log that the
    role's radio module answers and records the board in
    software/web-flasher/devices.json. The panel lists every registered module,
    including ones never seen in that browser. ble_test.py: retrying connect and a
    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
2026-10-09 Reset history in NVS, radio init diagnostics
    LisekOta records the reason for each boot (P power-on, B brownout, X panic,
    W watchdog, ...) in NVS, prints it at boot and reports it in the info JSON;
    usb-autoflash shows it and flags brownouts. The receiver logs what the
    LoRa-E5 answered when radio init fails.
    Found with it: lisek-R-90C0 on battery resets by brownout
    (PPPPPPBPPBPBPBPB) since Bluetooth runs.
    [led-receiver.ino, usb_autoflash.py]
2026-10-09 Lower peak current: BLE at 0 dBm, CPU at 80 MHz
    lisek-R-90C0 browned out on battery once Bluetooth was running (reset history
    ...BPPBPBPBPB). Bluetooth TX power goes from +3 to 0 dBm and the CPU from 240
    to 80 MHz on both boards; UART, LEDs and BLE work at 80 MHz (checked on the
    receiver: radio up, BLE info read).
    [fox-transmitter.ino, led-receiver.ino]
2026-10-09 ble_test: retry the first info read after a reboot, like the panel
    Verified at 80 MHz on lisek-R-90C0: BLE update 27 s (43 KiB/s), pending with
    rollback countdown after the reboot, confirmed.
    [ble_test.py]
2026-10-09 Panel: labelled Ustawienia and Aktualizuj/Wgraj ponownie buttons on each card
    Settings (channel count, LED mode, hiding) were only behind a small gear icon
    and the update icon was silently disabled when the device was current.
2026-10-09 Panel: paired devices usable without scanning
    Without advertisement watching (Linux, no flags) paired devices only became
    controllable after a 30 s poll found them. Now they are checked right away,
    Ustawienia/Aktualizuj connect on demand, and an unpaired device shows a
    labelled Połącz button.
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2026-10-15 Panel: remote debug log
    The page sends its events (startup and browser capabilities, requestDevice,
    connects with timing, device notifications, commands, every status change,
    toasts, JS errors, console errors/warnings) as GET log?s=&n=&d= to its own
    server; on mxg.sh they land in the nginx access log on la-casa and
    software/ota/remote-log.sh decodes them per session. No server change needed.
2026-10-15 Panel: hide 'Skanuj okolicę' where requestLEScan does not exist
    The remote log showed Bluefy (iOS) offering the scan button and then failing
    with 'Ta przeglądarka nie udostępnia Web Bluetooth requestLEScan'.
2026-10-15 Receiver: LoRa-E5 link at 115200 baud so the LEDs no longer lag
    At 9600 baud each received packet (LEN line + 64-hex RX line, ~111 chars)
    takes ~116 ms on the UART while the transmitter sends every 100 ms, so lines
    queued and the signal display fell further and further behind. fast_link()
    probes 115200, else switches the module from its 9600 default once
    (AT+UART=BR then AT+RESET; the module keeps it). Serial1 RX buffer 1024.
2026-10-15 OTA safety: data-path self-test before confirm, crash-loop guard
    - A freshly installed image is only confirmed after 4 KiB of random data went
    through the DATA characteristic and the device returned the matching
    SHA-256 ('test N' / 'test-ok:<hex>'), so an image with a broken update path
    is never kept. Older firmware answers 'unknown command' and is still
    confirmed as before. Panel has a pure-JS SHA-256 fallback (no crypto.subtle
    on plain http).
    - Crash-loop guard (RTC memory): three panic/watchdog resets in a row, each
    within 60 s of boot, boot the other app slot if it holds a valid image; if
    that was already tried, the device stays in a Bluetooth-only safe mode that
    can stil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
2026-10-15 Panel: reconnect after the device reboot with a fresh link
    The remote log showed iOS (Bluetooth Browser) stuck on 'Restart…': after the
    update reboot the app kept the old link and startNotifications timed out on
    every retry. Disconnect before each try, log the retries, and retry for 150 s
    (well inside the 5 min rollback window).
2026-10-15 Faster discovery: 211 ms advertising for 5 min after boot and disconnect
    iOS pickers took up to 24 s to list a device advertising once a second. Use
    Apple's recommended 211.25 ms interval for 5 minutes after power-on and after
    every disconnect (setup and updates, incl. the reconnect after the update
    reboot), then back to 1 s for battery. Panel logs the browser's Bluetooth API
    surface (bt-api) to find a scanning API on iOS apps.
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2026-10-15 OTA: compressed images, device log over BLE, confirm without radio; iOS fixes
    - Compressed images (LSK2, zlib, 64% of the plain size): inflated on the device
    by the ESP32 ROM tinfl into a 32 KB window while writing; header size/SHA-256
    are of the plain image. sign.py writes .lsk (LSK1, for older firmware) and
    .lskz; the panel sends .lskz when the device lists the 'z' capability.
    The streaming loop was compiled on the host against miniz and reproduces
    both images (SHA-256 matches) for 20..4096-byte chunks.
    - Device log: last 4 KB of messages (LisekOta::logf/logln; sketches log
    through it except per-packet/periodic lines), read with 'log <offset>'
    chunks; panel 'Dziennik' button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
2026-10-15 Receiver: update progress uses all 7 LEDs evenly, full until the reboot
    1 + done*6/total lit LED6 (green) only after 83% and LED7 only at 100%, the
    moment the update stopped counting as in progress, so both greens seemed to
    come on together at the end. Now LED k lights after (k-1)/7 of the image and
    updating() includes the installed state, so the bar stays full until the
    reboot.
